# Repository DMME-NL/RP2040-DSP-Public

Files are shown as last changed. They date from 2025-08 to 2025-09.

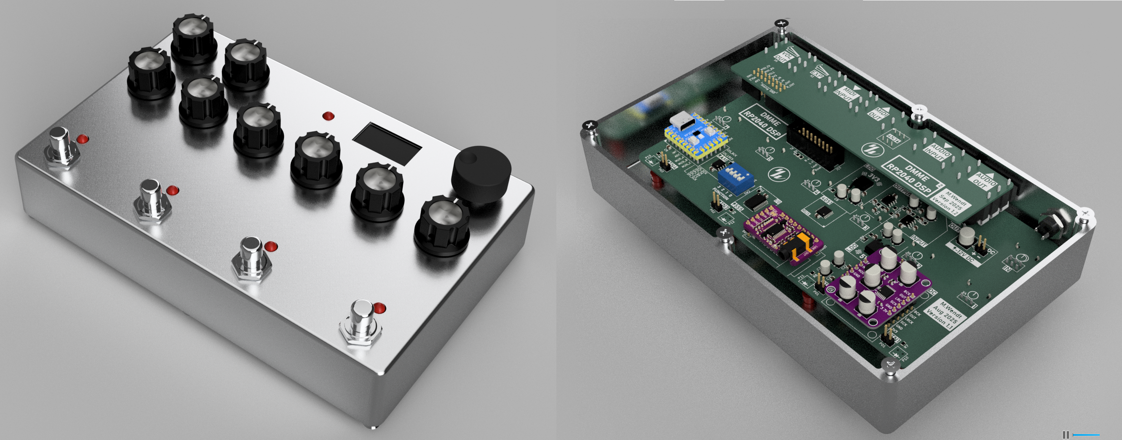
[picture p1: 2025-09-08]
Hardware/V1.2_Enclosure_Render.png

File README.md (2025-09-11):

# 🎸✨ RP2040-DSP: Multi-Effect 24-bit Audio Processor

## 🧩 Summary

RP2040-DSP is a fully modular 24-bit stereo audio effects processor built on the Raspberry Pi RP2040 microcontroller. It is designed to run real-time audio effects for guitar and other instruments, including cabinet simulation for headphone or direct recording use.

The firmware architecture is modular, supporting multiple effects that can be stacked and configured flexibly.

V1 0_Enclosure_Render

---

## 🎛️ Features & Functionality

- **24-bit stereo signal path** at 48 kHz.
- **Up to 3 simultaneous effects**, each fully configurable and ordered in series.
- Modular effect system with easy header-based integration.
- Real-time parameter control via 6 potentiometers and rotary encoder.
- OLED display for clear feedback and editing.
- Footswitch-controlled bypass and slot toggling.
- Tap-tempo support for modulation and delay-based effects.
- VU meter and signal level visualization.
- Two expression pedal inputs:
  - One dedicated to master volume.
  - One assignable to any effect parameter.

> **Note:** Total number of simultaneous effects is limited by to CPU resources and their type.
> Some features, like MIDI and expression pedal, have not been implemented as of now.

---

## 🎚️ Available Effects

### Modulation

- **Chorus:** 1, 2, or 3 short modulated delay lines with optional stereo spread via phase offset.
- **Flanger:** Single short modulated delay with optional stereo phase offset.
- **Phaser:** Multi-stage all-pass filter network with optional stereo phase offset.
- **Tremolo:** Stereo amplitude modulation with optional stereo phase offset.

### Time-based

- **Delay:** Long stereo delay with different signal path and feedback modes, uses SPI RAM buffering. 
- **Reverb:** Hall / room type reverb based on comb and all-pass filters with modualr buffer size.

### Tone shaping

- **EQ:** Multi-band EQ similar to a guitar tone-stack. Includes range control for mid frequency.

### Dynamic

- **Compressor:** Adjustable threshold, ratio, attack, release, and makeup gain.
- **Distortion, Overdrive, Fuzz:** Various analog-inspired waveshaping algorithms with tone filtering similar to the EQ.

### Speaker & Preamp simulation

- **Cabinet Sim (Speaker Sim):** Parametric approximation of guitar cabinet. Includes multiple controls for tone shaping.
- **Preamp:** Simulates preamp coloration and dynamic shaping (Marshall, VOX, Fender).

### Work-in-Progress

- **Vibrato:** Pure pitch modulation using short-time delay interpolation.

---

## ⚡ Software Architecture and Design Choices

- **Header-based modularity:** Each effect is self-contained in its own header file (`*.h`), following a consistent structure:
  - `init_*()`
  - `load_*_parms_from_memory()`
  - `update_*_params_from_pots()`
  - `process_audio_*_sample()`
- **Pot and memory sync:** Parameters load from stored memory and dynamically update when pots change. Holding down the TAP button for 5 seconds stores all the effects and settings to flash, so they can be receovered after power-down.
- **Optimized math:** Using fixed point math and lightweight approximations, reducing CPU usage without harming audio quality.
- **Dual-core structure:**
  - **Core 0:** Dedicated to real-time audio sample processing.
  - **Core 1:** Handles UI, pot reading, OLED updates.
- **SPI RAM (APS6404L):** Used for long delay lines, minimizing local RAM usage.

> **Note:** I am an embedded electronics engineer and this is my first large software project in C.
> - *.c files frustrate me because I always forget to change them after modifying a header...
> - There will be some dependencies between variabled defined and used in different *.h header files.
> - I am using global variables in places where I might not need them / should not use them. 
> - There will be inconsistencies in coding style and methods as I have been learning a lot during the course of this project.
> - This has been some journey! I intend to clean up the code once all the features are there (I promisse...)
> - I will likely forget to clean up the code, and continue development on the newer hardware versions / platforms instead...

---

## 💻 CPU Usage (250 MHz OC, 48 kHz stereo)

| Effect | CPU Peak Usage (%) |
|---|---|
| Chorus | 21% |
| Compressor | 11% |
| Delay | 49% |
| Distortion | 19% |
| EQ | 14% |
| Flanger | 18% |
| Fuzz | 24% |
| Overdrive | 24% |
| Phaser | 30% |
| Preamp | 52% |
| Reverb | 55% |
| Speaker Sim | 25% |
| Tremolo | 5% |
| Vibrato | WIP |

> **Note:** Figures above are with common effects (overdrive, preamp, etc..) processed in mono.
> All effects can be processed as fully stereo by chaging the STEREO definition in the main.c file.
> Actual performace allows the Reveb and Delay to run simultaneously depending on the sample buffer size!
---

## 🖥️ User Interface Overview

- Parameter abbreviation display with full name and value popup on change.
- Encoder-controlled effect slot assignment and navigation.
- LED blink feedback for modulation or delays.
- Footswitch toggling per effect slot, with LED status indication.
- VU meter visualizing signal levels or compressor gain reduction in real time.
- Delay UI with time settings in [ms] or tap-tempo with selectable fractions.

---

## 🔧 Hardware Overview

> Version 1.2

This design can be ordered directly from PCBWay, including assembly of the SMD components.
See the hardware folders for a complete bill of materials (ibom.html) that also includes all the modules and THT parts. 
If you do not want to use PCBway, or refuse to give me the please of a small 10% commision via their services; the KiCAD project, gerbers, and BOM are also located in this repository.

PCBway profile: https://www.pcbway.com/project/member/?bmbno=88DFECEC-9511-40

Mainboard V1.2:  https://www.pcbway.com/project/shareproject/RP2040_Multi_effect_Pedal_Mainboard_30e99e7d.html

Mainboard V2.1:  https://www.pcbway.com/project/shareproject/RP2040_Multi_effect_Pedal_Mainboard_V2_1_08d54258.html

Daughterboard:  https://www.pcbway.com/project/shareproject/RP2040_Multi_effect_Pedal_Daughterboard_25cda6b7.html

- **ADC:** PCM1808 stereo ADC module.
- **DAC:** PCM5102 stereo DAC module.
- **Regulated power:** LM78xx linear regulators.
- **Form factor:** Designed for Hammond 1950DD enclosure.
- **Input voltage:** 9–12 V DC.
- **Expression pedals:** 2 inputs, configurable.

❗NOTE: PCM1808 inputs are not attenuated and will clip with high-output pickups. The ADC has an input RC filter on-board that can be replaced by a ~100k series resistance to provide ~2x attenuation.

> **Later versions:**  PCM3060 version are have not yet been fully tested!. The concept was proven on a different PCB design and identical schematic - without any changes to the software. Although, I did not test this PCB design specificaly, it should work perfectly fine.

---

## 📜 License

The full text of the license should be found in LICENSE.txt, included as part of this repository.

This library and all accompanying code, examples, information and documentation is Copyright (C) 2025 Milan Wendt

This program is free software: you can redistribute it and/or modify it under the terms of the GNU General Public
License, version 3 as published by the Free Software Foundation.

This program is distributed in the hope that it will be useful, but WITHOUT ANY WARRANTY; without even the implied
warranty of MERCHANTABILITY or FITNESS FOR A PARTICULAR PURPOSE. See the GNU General Public License for more details.

You should have received a copy of the GNU General Public License along with this program. If not,
see <https://www.gnu.org/licenses/>.

---

🎸 Enjoy building and tweaking your own ultimate guitar multi-effects processor with RP2040-DSP!

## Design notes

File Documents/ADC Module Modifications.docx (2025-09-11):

# PCM1808 Module

This mode can have some issues depending on the vendor.

Input Filter and Attenuation

Firstly, to make sure a high-output guitar or bass does not cause unintended clipping of the signal, it is recommended to replace the input filter on the board with a 100k resistor:

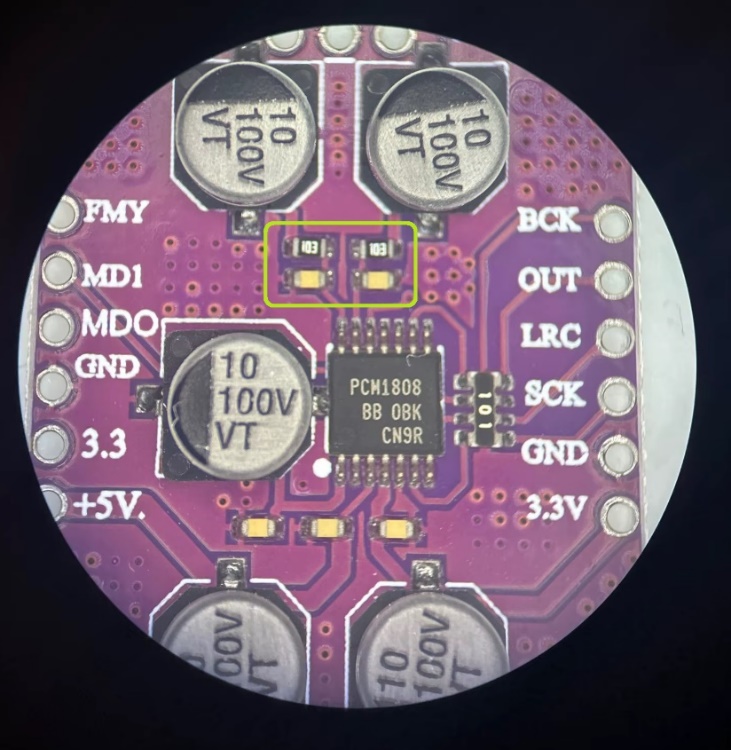
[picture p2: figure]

Simply removing the existing 0603 parts allows for soldering an 0805 resistor on the existing pads. If needed, it can placed diagonally making sure to not short the ground pad.

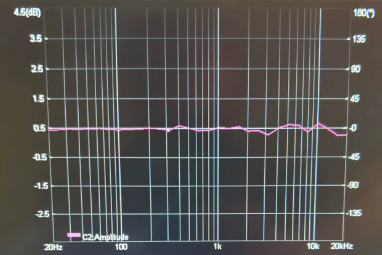
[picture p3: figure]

The modules I ordered came with wrong filter values of 10k + 10nF causing a low-pass filter of ~1.6kHz. So, replacement of these parts might be necessary depending on the vendor and manufacturer.

This bode-plot shows the frequency response if you simply short the resistor and remove the capacitor.

100k is safe, but you can play with the value to get the input level and range your application / guitar likes.

Higher values → Lower input, reduce clipping
Lower values → Higher input, improved SNR

Wrong PCB layout!

My second order arrived with a mistake in the PCB layout! (left image is the a good layout)

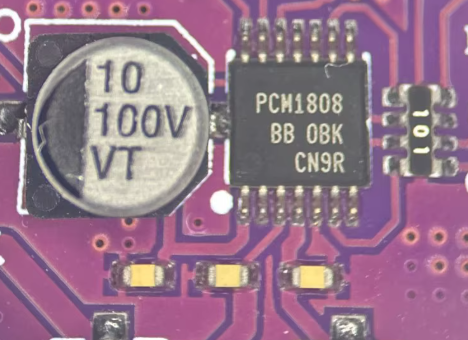
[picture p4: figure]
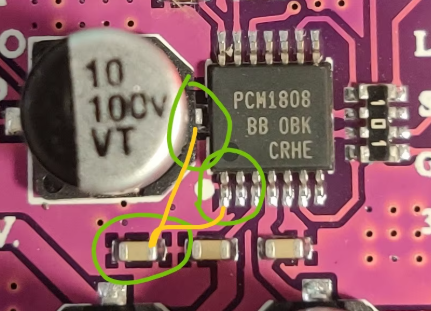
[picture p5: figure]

The right image is from another customer that tries to depict the intended traces.
This layout error cuases the bias voltage pin of the ADC to be shorted to ground!
The board will not work like this..

One way to salvage it is to cut the traces / ground plane arount the pin and solder a THT 10uF capacitor to GND. Make sure to also add a ceramic 100nF cap (just to follow the datasheet recommended values).

Optionally, the pin can be lifted instead.
Capacitor rating of > 15V should be more than enough.

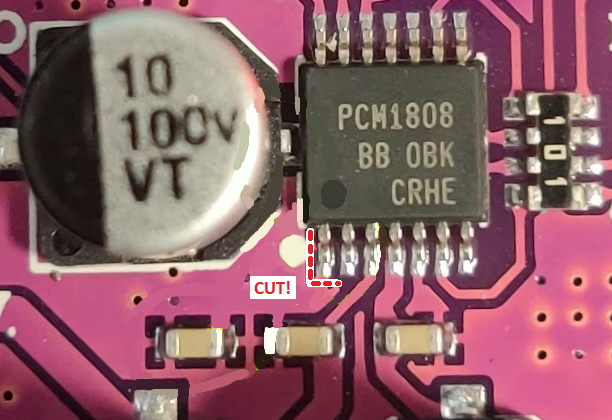
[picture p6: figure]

Just make sure to disconnect it from ground and add the two capacitors!

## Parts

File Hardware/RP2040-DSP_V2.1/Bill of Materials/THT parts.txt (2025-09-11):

RP2040 Zero:
https://nl.aliexpress.com/item/1005006865919374.html

128x64_OLED:
https://nl.aliexpress.com/item/1005006262908701.html

4N36_DIP-6_W7.62mm:
https://nl.aliexpress.com/item/1005007501324743.html

Potentiometer_Alpha_RD902F-40-00D:
https://nl.aliexpress.com/item/1005008575940833.html

Potentiometer_Alpha_RD901F-40-00D:
https://nl.aliexpress.com/item/1005005661105692.html

RotaryEncoder_Alps_EC11:
https://nl.aliexpress.com/item/4000669429876.html

Jack 6.35mm Horizontal NYS215:
https://nl.aliexpress.com/item/32963629992.html

IDC-Header_2x08_P2.54mm_Vertical	
https://nl.aliexpress.com/item/1005005963522730.html

SW_DIP_SPSTx04:
https://nl.aliexpress.com/item/10000004737395.html

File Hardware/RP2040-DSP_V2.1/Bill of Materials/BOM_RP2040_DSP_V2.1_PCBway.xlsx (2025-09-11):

 |  |  | RP2040 DSP V1.2 PCS BOM (Sample Bill of Materials)
Item # | *Designator | *Qty | Manufacturer | *Mfg Part # | Description / Value | *Package/Footprint | Type | Your Instructions / Notes
24 | C1 | 1 | Würth Elektronik | 865080343009 | CAP ALUM 100UF 20% 16V SMD | C_Elec 6.3mm | SMD | Replace with different part with same specs is accepted
16 | C17,C16 | 2 | Murata Electronics | GRM2165C1H101JA01J | CAP CER 100PF 50V C0G/NP0 0805 | 0805 | SMD | Replace with different part with same specs is accepted
8 | C21,C25,C3,C18,C12,C2,C5,C11,C23,C24,C13,C20,C10,C19,C6,C4,C29,C31 | 18 | Murata Electronics | GCM21BR71H104KA37K | CAP CER 0.1UF 50V X7R 0805 | 0805 | SMD | Replace with different part with same specs is accepted
4 | C28,C15,C8,C7,C26,C27,C22,C34,C14,C32,C33 | 11 | Würth Elektronik | 865080440002 | CAP ALUM 10UF 20% 25V SMD | C_Elec 4.3mm | SMD | Replace with different part with same specs is accepted
10 | C9,C30 | 2 | Murata Electronics | GRM216R61E105KA12D | CAP CER 1UF 25V X5R 0805 | 0805 | SMD | Replace with different part with same specs is accepted
20 | D1 | 1 | KYOCERA AVX | SD0805S040S0R5 | DIODE SCHOTTKY 40V 500MA 0805 | 0805 | SMD | Replace with different part with same specs is accepted
9 | D2,D3 | 2 | Kingbright | APT2012SRCPRV | LED RED CLEAR CHIP SMD | 0805 | SMD | Replace with different part with same specs is accepted
25 | R14 | 1 | YAGEO | RC0805FR-07220KL | RES 220K OHM 1% 1/8W 0805 | 0805 | SMD | Replace with different part with same specs is accepted
45 | R15 | 1 | YAEGO | RC0805FR-07680RL | RES 680 OHM 1% 1/8W 0805 | 0805 | SMD | Replace with different part with same specs is accepted
44 | R16 | 1 | YAEGO | RC0805FR-0710RL | RES 10 OHM 1% 1/8W 0805 | 0805 | SMD | Replace with different part with same specs is accepted
37 | R17 | 1 | YAEGO | RC0805FR-0733RL | RES 33 OHM 1% 1/8W 0805 | 0805 | SMD | Replace with different part with same specs is accepted
41 | R18 | 1 | YAEGO | RC0805FR-07220RL | RES 220 OHM 1% 1/8W 0805 | 0805 | SMD | Replace with different part with same specs is accepted
5 | R5,R22,Rp1,R6,R21,R20,R19 | 7 | YAEGO | RC0805FR-0710KL | RES 10K OHM 1% 1/8W 0805 | 0805 | SMD | Replace with different part with same specs is accepted
1 | R7,R1,R2,R9,R13,R10,R4,R3,R8 | 9 | YAEGO | RC0805FR-071KL | RES 1K OHM 1% 1/8W 0805 | 0805 | SMD | Replace with different part with same specs is accepted
2 | Rb1,Rb4,Rb3,Rb2 | 4 | YAEGO | RC0805FR-071ML | RES 1M OHM 1% 1/8W 0805 | 0805 | SMD | Replace with different part with same specs is accepted
3 | Rg1,Rg2,R11,R12 | 4 | YAEGO | RC0805FR-074K7L | RES 4.7K OHM 1% 1/8W 0805 | 0805 | SMD | Replace with different part with same specs is accepted
13 | U1 | 1 | Texas Instruments | LM78M05CDT/NOPB | IC REG LINEAR 5V 500MA TO252-3 | TO-252-3 | SMD | Replace with different part with same specs is accepted
17 | U10,U9 | 2 | Texas Instruments | NE5532DR | IC OPAMP GP 2 CIRCUIT 8SOIC | SOIC-8 | SMD | Replace with different part with same specs is accepted
12 | U13 | 1 | Advanced Monolithic Systems | AMS1117CD-3.3 | IC REG LINEAR 3.3V 1A TO252 | TO-252-3 | SMD | Replace with different part with same specs is accepted
7 | U2 | 1 | Texas Instruments | PCM3060PWR | IC AUDIO CODEC 24BIT SER 28TSSOP | TSSOP-28 | SMD
22 | U3 | 1 | Texas Instruments | CD4051BPWR | IC MUX 8:1 240OHM 16TSSOP | TSSOP-16 | SMD
14 | U5 | 1 | AP Memory | APS6404L-3SQR-SN | DRAM 64Mb QSPI PSRAM Sync Serial x1/x4 SDR | SOP-8 | SMD
21 | U6 | 1 | Texas Instruments | PCA9555DB | IC XPNDR 400KHZ I2C SMBUS 24SSOP | SSOP-24 | SMD
Need a quick and accurante quote? Need an efficient production? Please read SMT Ordering Necessary Files & Info in 1 minute. Thank you very much! (https://www.pcbway.com/smt_ordering_guide.html)
Click for Instructions on How to Create a BOM (https://www.pcbway.com/blog/PCB_Assembly/How_to_Build_a_BOM__Bill_Of_Materials_.html)

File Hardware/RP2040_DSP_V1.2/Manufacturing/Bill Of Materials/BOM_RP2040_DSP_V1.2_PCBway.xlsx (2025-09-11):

 |  |  | RP2040 DSP V1.2 PCS BOM (Sample Bill of Materials)
Item # | *Designator | *Qty | Manufacturer | *Mfg Part # | Description / Value | *Package/Footprint | Type | Your Instructions / Notes
1 | C1 | 1 | Würth Elektronik | 865080343009 | CAP ALUM 100UF 20% 16V SMD | C_Elec 6.3mm | SMD | Replace with different part with same specs is accepted
2 | C15,C8,C7,C26,C27,C23,C22,C14,C32,C33 | 10 | Würth Elektronik | 865080440002 | CAP ALUM 10UF 20% 25V SMD | C_Elec 4.3mm | SMD | Replace with different part with same specs is accepted
3 | C17,C16 | 2 | Murata Electronics | GRM2165C1H101JA01J | CAP CER 100PF 50V C0G/NP0 0805 | 0805 | SMD | Replace with different part with same specs is accepted
4 | C28,C21,C25,C3,C18,C12,C2,C5,C11,C24,C13,C20,C10,C19,C6,C4,C29,C31 | 18 | Murata Electronics | GCM21BR71H104KA37K | CAP CER 0.1UF 50V X7R 0805 | 0805 | SMD | Replace with different part with same specs is accepted
5 | C9,C30 | 2 | Murata Electronics | GRM216R61E105KA12D | CAP CER 1UF 25V X5R 0805 | 0805 | SMD | Replace with different part with same specs is accepted
6 | D1 | 1 | KYOCERA AVX | SD0805S040S0R5 | DIODE SCHOTTKY 40V 500MA 0805 | 0805 | SMD | Replace with different part with same specs is accepted
7 | D2,D3 | 2 | Kingbright | APT2012SRCPRV | LED RED CLEAR CHIP SMD | 0805 | SMD | Replace with different part with same specs is accepted
8 | R15 | 1 | YAEGO | RC0805FR-07680RL | RES 680 OHM 1% 1/8W 0805 | 0805 | SMD | Replace with different part with same specs is accepted
9 | R16 | 1 | YAEGO | RC0805FR-0710RL | RES 10 OHM 1% 1/8W 0805 | 0805 | SMD | Replace with different part with same specs is accepted
10 | R17 | 1 | YAEGO | RC0805FR-0733RL | RES 33 OHM 1% 1/8W 0805 | 0805 | SMD | Replace with different part with same specs is accepted
11 | R18 | 1 | YAEGO | RC0805FR-07220RL | RES 220 OHM 1% 1/8W 0805 | 0805 | SMD | Replace with different part with same specs is accepted
12 | R5,Rp1,R6 | 3 | YAEGO | RC0805FR-0710KL | RES 10K OHM 1% 1/8W 0805 | 0805 | SMD | Replace with different part with same specs is accepted
13 | R7,R1,R2,R9,R13,R10,R4,R3,R8 | 9 | YAEGO | RC0805FR-071KL | RES 1K OHM 1% 1/8W 0805 | 0805 | SMD | Replace with different part with same specs is accepted
14 | Rb1,Rb4,Rb3,Rb2 | 4 | YAEGO | RC0805FR-071ML | RES 1M OHM 1% 1/8W 0805 | 0805 | SMD | Replace with different part with same specs is accepted
15 | Rg1,Rg2,R11,R12 | 4 | YAEGO | RC0805FR-074K7L | RES 4.7K OHM 1% 1/8W 0805 | 0805 | SMD | Replace with different part with same specs is accepted
16 | U1 | 1 | Texas Instruments | LM78M05CDT/NOPB | IC REG LINEAR 5V 500MA TO252-3 | TO-252-3 | SMD | Replace with different part with same specs is accepted
17 | U10,U9 | 2 | Texas Instruments | NE5532DR | IC OPAMP GP 2 CIRCUIT 8SOIC | SOIC-8 | SMD | Replace with different part with same specs is accepted
18 | U13 | 1 | Advanced Monolithic Systems | AMS1117CD-3.3 | IC REG LINEAR 3.3V 1A TO252 | TO-252-3 | SMD | Replace with different part with same specs is accepted
19 | U3 | 1 | Texas Instruments | CD4051BPWR | IC MUX 8:1 240OHM 16TSSOP | TSSOP-16 | SMD
20 | U5 | 1 | AP Memory | APS6404L-3SQR-SN | DRAM 64Mb QSPI PSRAM Sync Serial x1/x4 SDR | SOP-8 | SMD
21 | U6 | 1 | Texas Instruments | PCA9555DB | IC XPNDR 400KHZ I2C SMBUS 24SSOP | SSOP-24 | SMD
Need a quick and accurante quote? Need an efficient production? Please read SMT Ordering Necessary Files & Info in 1 minute. Thank you very much! (https://www.pcbway.com/smt_ordering_guide.html)
Click for Instructions on How to Create a BOM (https://www.pcbway.com/blog/PCB_Assembly/How_to_Build_a_BOM__Bill_Of_Materials_.html)

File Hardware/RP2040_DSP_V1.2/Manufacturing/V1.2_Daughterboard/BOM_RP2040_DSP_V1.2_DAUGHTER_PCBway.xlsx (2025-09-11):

 |  |  | RP2040 DSP V1.2 PCS BOM (Sample Bill of Materials)
Item # | *Designator | *Qty | Manufacturer | *Mfg Part # | Description / Value | *Package/Footprint | Type | Your Instructions / Notes
1 | C32,C33 | 10 | Würth Elektronik | 865080440002 | CAP ALUM 10UF 20% 25V SMD | C_Elec 4.3mm | SMD | Replace with generic part with same specs is accepted
2 | C31 | 18 | Murata Electronics | GCM21BR71H104KA37K | CAP CER 0.1UF 50V X7R 0805 | 0805 | SMD | Replace with generic part with same specs is accepted
3 | R15 | 1 | YAEGO | RC0805FR-07680RL | RES 680 OHM 1% 1/8W 0805 | 0805 | SMD | Replace with generic part with same specs is accepted
4 | R16 | 1 | YAEGO | RC0805FR-0710RL | RES 10 OHM 1% 1/8W 0805 | 0805 | SMD | Replace with generic part with same specs is accepted
5 | R17 | 1 | YAEGO | RC0805FR-0733RL | RES 33 OHM 1% 1/8W 0805 | 0805 | SMD | Replace with generic part with same specs is accepted
6 | R18 | 1 | YAEGO | RC0805FR-07220RL | RES 220 OHM 1% 1/8W 0805 | 0805 | SMD | Replace with generic part with same specs is accepted
Need a quick and accurante quote? Need an efficient production? Please read SMT Ordering Necessary Files & Info in 1 minute. Thank you very much! (https://www.pcbway.com/smt_ordering_guide.html)
Click for Instructions on How to Create a BOM (https://www.pcbway.com/blog/PCB_Assembly/How_to_Build_a_BOM__Bill_Of_Materials_.html)

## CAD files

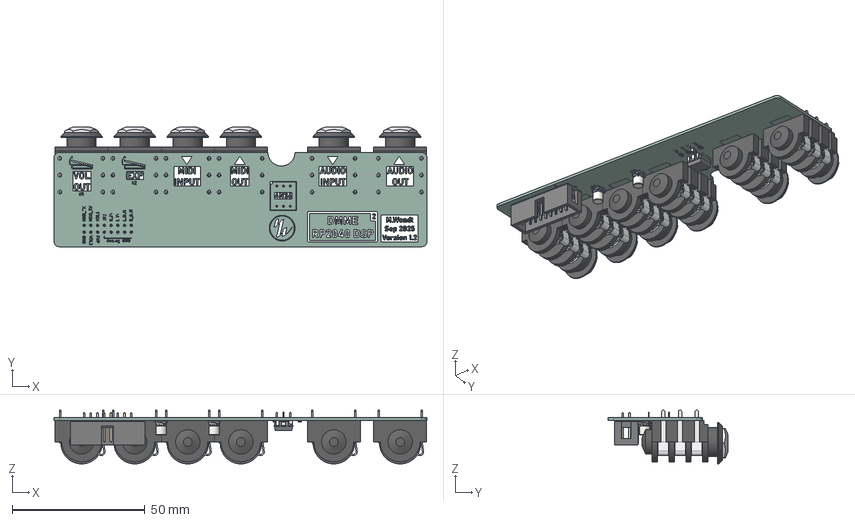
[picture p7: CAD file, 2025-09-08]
Hardware/Enclosure/RP2040_DSP_V1.2_Daughter.step
140.5 x 45.0 x 20.3 mm
Jack Socket x 6
Jack Nut x 6
Jack Nut Washer x 6
C_Elec_4x5.4 x 2
R_0805_2012Metric x 4
C_0805_2012Metric
IDC-Header_2x08_P2.54mm_Vertical
DIP-6_W7.62mm
RP2040_DSP_V1.2_silkscreen
RP2040_DSP_V1.2_PCB

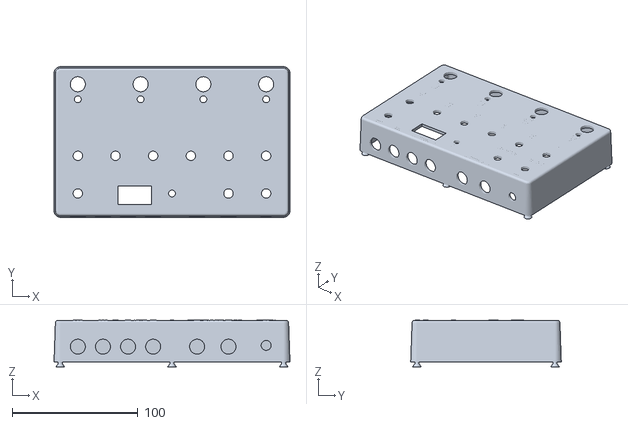
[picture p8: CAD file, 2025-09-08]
Hardware/Enclosure/RP2040 - MultEffect V1.2 Case.stl
188.0 x 120.0 x 37.1

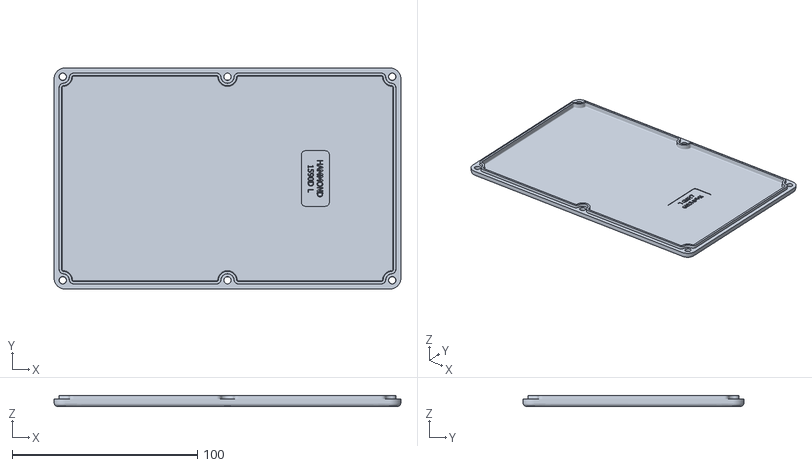
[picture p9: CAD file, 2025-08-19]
Hardware/Enclosure/RP2040 - MultEffect V1.2 Lid.stl
187.5 x 119.5 x 5.90

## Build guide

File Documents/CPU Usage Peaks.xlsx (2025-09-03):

Author: | Milan Wendt |  | Fs: | 48000 | Hz
Date: | 2025-09-02 |  | Limit | 10 | ms
 |  |  | Clock: | 250 | MHz
 |  | 128 | samples | 64 | samples | 32 | samples | 24 | samples | 16 | samples | 8 | samples
 | Effect | Peak | Actual | Peak | Actual | Peak | Actual | Peak | Actual | Peak | Actual | Peak | Actual | Note
 | Idle | 2% |  | 2% |  | 3% |  | 3% |  | 4% |  | 5%
 | Chorus | 16% | 14% | 16% | 14% | 20% | 18% | 24% | 21% | 26% | 24% | 21% | 19%
 | Compressor | 11% | 9% | 12% | 10% | 12% | 10% | 14% | 11% | 21% | 19% | 19% | 17%
 | Delay | 40% | 38% | 42% | 40% | 47% | 45% | 52% | 49% | 60% | 58% | 75% | 73%
 | Distortion | 20% | 18% | 20% | 18% | 21% | 19% | 22% | 19% | 23% | 21% | 24% | 22%
 | Equalizer | 15% | 13% | 15% | 13% | 15% | 13% | 17% | 14% | 17% | 15% | 19% | 17%
 | Flanger | 19% | 17% | 19% | 17% | 20% | 18% | 21% | 18% | 21% | 19% | 23% | 21%
 | Fuzz | 24% | 22% | 25% | 23% | 25% | 23% | 27% | 24% | 29% | 27% | 30% | 28%
 | Overdrive | 24% | 22% | 25% | 23% | 26% | 24% | 27% | 24% | 27% | 25% | 28% | 26%
 | Phaser | 28% | 26% | 28% | 26% | 30% | 28% | 33% | 30% | 50% | 48% | 60% | 58%
 | Pre - Fend | 52% | 50% | 53% | 51% | 55% | 53% | 54% | 51% | 57% | 55% | 56% | 54%
 | Pre - VOX | 51% | 49% | 52% | 50% | 52% | 50% | 54% | 51% | 56% | 54% | 58% | 56%
 | Pre - Marsh | 52% | 50% | 53% | 51% | 54% | 52% | 55% | 52% | 55% | 53% | 58% | 56%
 | Pre - Sol | 54% | 52% | 55% | 53% | 57% | 55% | 58% | 55% | 58% | 56% | 58% | 56%
 | Reverb | 56% | 54% | 56% | 54% | 58% | 56% | 59% | 56% | 60% | 58% | 62% | 60%
 | Cab Sim | 26% | 24% | 26% | 24% | 27% | 25% | 28% | 25% | 29% | 27% | 31% | 29%
 | Tremolo | 6% | 4% | 6% | 4% | 7% | 5% | 8% | 5% | 8% | 6% | 21% | 19%
 | Vibrato |  | -2% |  | -2% |  | -2% |  | -3% |  | -2% |  | -2% | Not implemented
 | Buffer time | 2.67 | ms | 1.33 | ms | 0.67 | ms | 0.50 | ms | 0.33 | ms | 0.17 | ms
 | Stereo | 5.33 | ms | 2.67 | ms | 1.33 | ms | 1.00 | ms | 0.67 | ms | 0.33 | ms
 | Measured | 6.1 | ms | 3.5 | ms | 2.2 | ms | 1.8 | ms | 1.5 | ms | 1.2 | ms
 | Max series | 1.64 | units | 2.86 | units | 4.55 | units | 5.56 | units | 6.67 | units | 8.33 | units
 | Round up | 2.00 | units | 3.00 | units | 5.00 | units | 6.00 | units | 7.00 | units | 9.00 | units
 | Delay | 12.2 | ms | 10.5 | ms | 11 | ms | 10.8 | ms | 10.5 | ms | 10.8 | ms
 | Effect / Samples | 128 | 64 | 32 | 24 | 16 | 8
 | Idle | 0% | 0% | -1% | -1% | -2%
 | Chorus | 0% | 0% | -4% | -8% | -10%
 | Compressor | 0% | -1% | -1% | -3% | -10%
 | Delay | 0% | -2% | -7% | -12% | -20%
 | Distortion | 0% | 0% | -1% | -2% | -3%
 | Equalizer | 0% | 0% | 0% | -2% | -2%
 | Flanger | 0% | 0% | -1% | -2% | -2%
 | Fuzz | 0% | -1% | -1% | -3% | -5%
 | Overdrive | 0% | -1% | -2% | -3% | -3%
 | Phaser | 0% | 0% | -2% | -5% | -22%
 | Preamp | 0% | -1% | -3% | -4% | -4%
 | Reverb | 0% | 0% | -2% | -3% | -4%
 | Cab Sim | 0% | 0% | -1% | -2% | -3%
 | Tremolo | 0% | 0% | -1% | -2% | -2%
 | Vibrato | 0% | 0% | 0% | 0% | 0%

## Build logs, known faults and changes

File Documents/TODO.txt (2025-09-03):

Selected for Development:
[V] Tap tempo for delay
[V] Fractions for delay
[V] Store settings
[V] Wear leveling in Flash
[ ] Vibrato

Nice to Have:
[ ] MIDI
[ ] Fix modulation artifacts
[ ] Wah-Wah

Not Required:
[ ] SPI RAM optimize
[ ] Effects optimize
[ ] Expression Pedal
[ ] Tap tempo for modulation effects

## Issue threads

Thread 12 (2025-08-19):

SPI RAM: Optimize speed

DMME-NL, 2025-08-19:
- Can we increase RAM clock?
Currently, response delay of MISO is causing setup/hold time issues when reading the data.
Perhaps, the sampling of the data line can be delayed / moved in relation to the generated clock.
Writing at higher speeds seems to be fine.

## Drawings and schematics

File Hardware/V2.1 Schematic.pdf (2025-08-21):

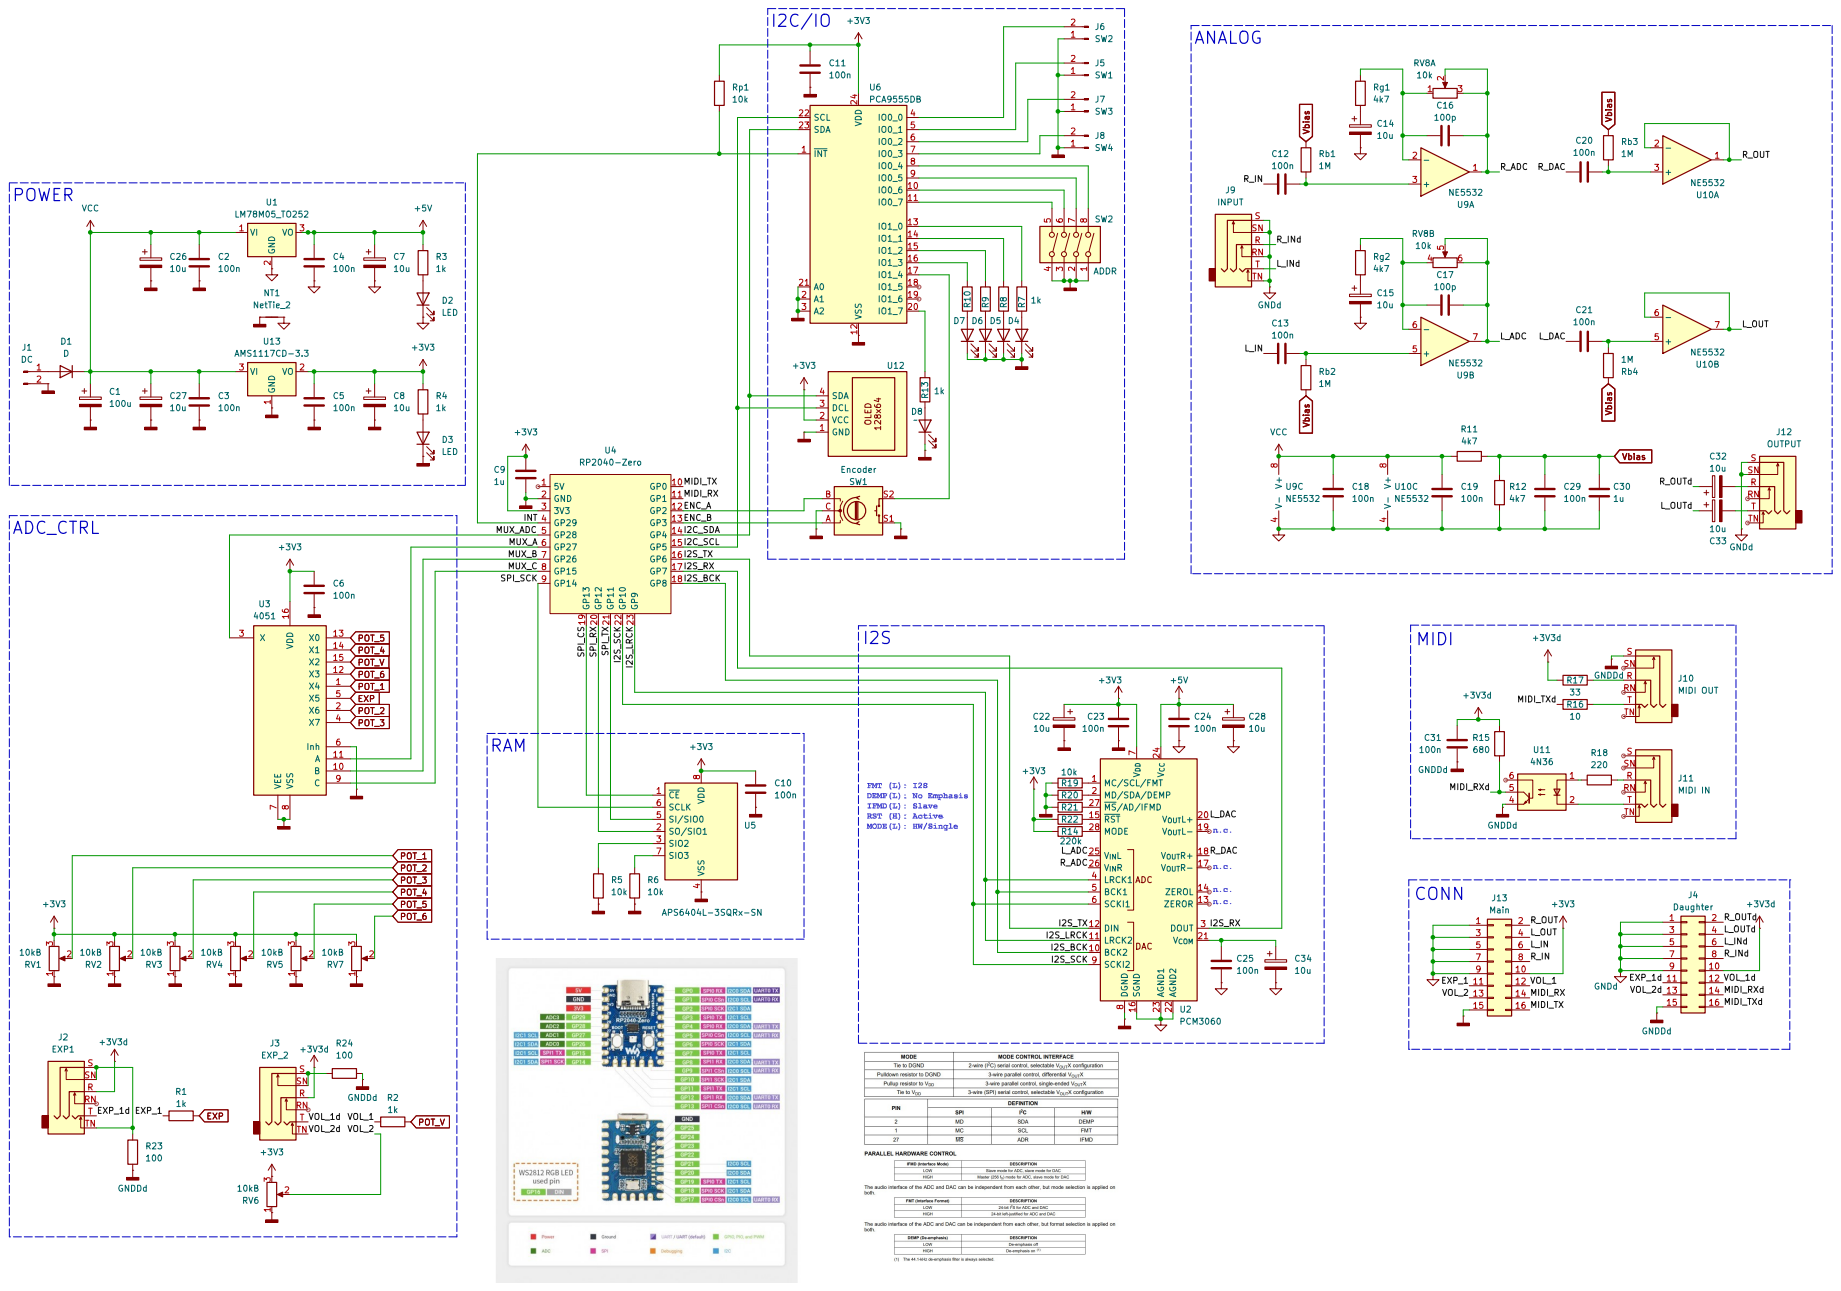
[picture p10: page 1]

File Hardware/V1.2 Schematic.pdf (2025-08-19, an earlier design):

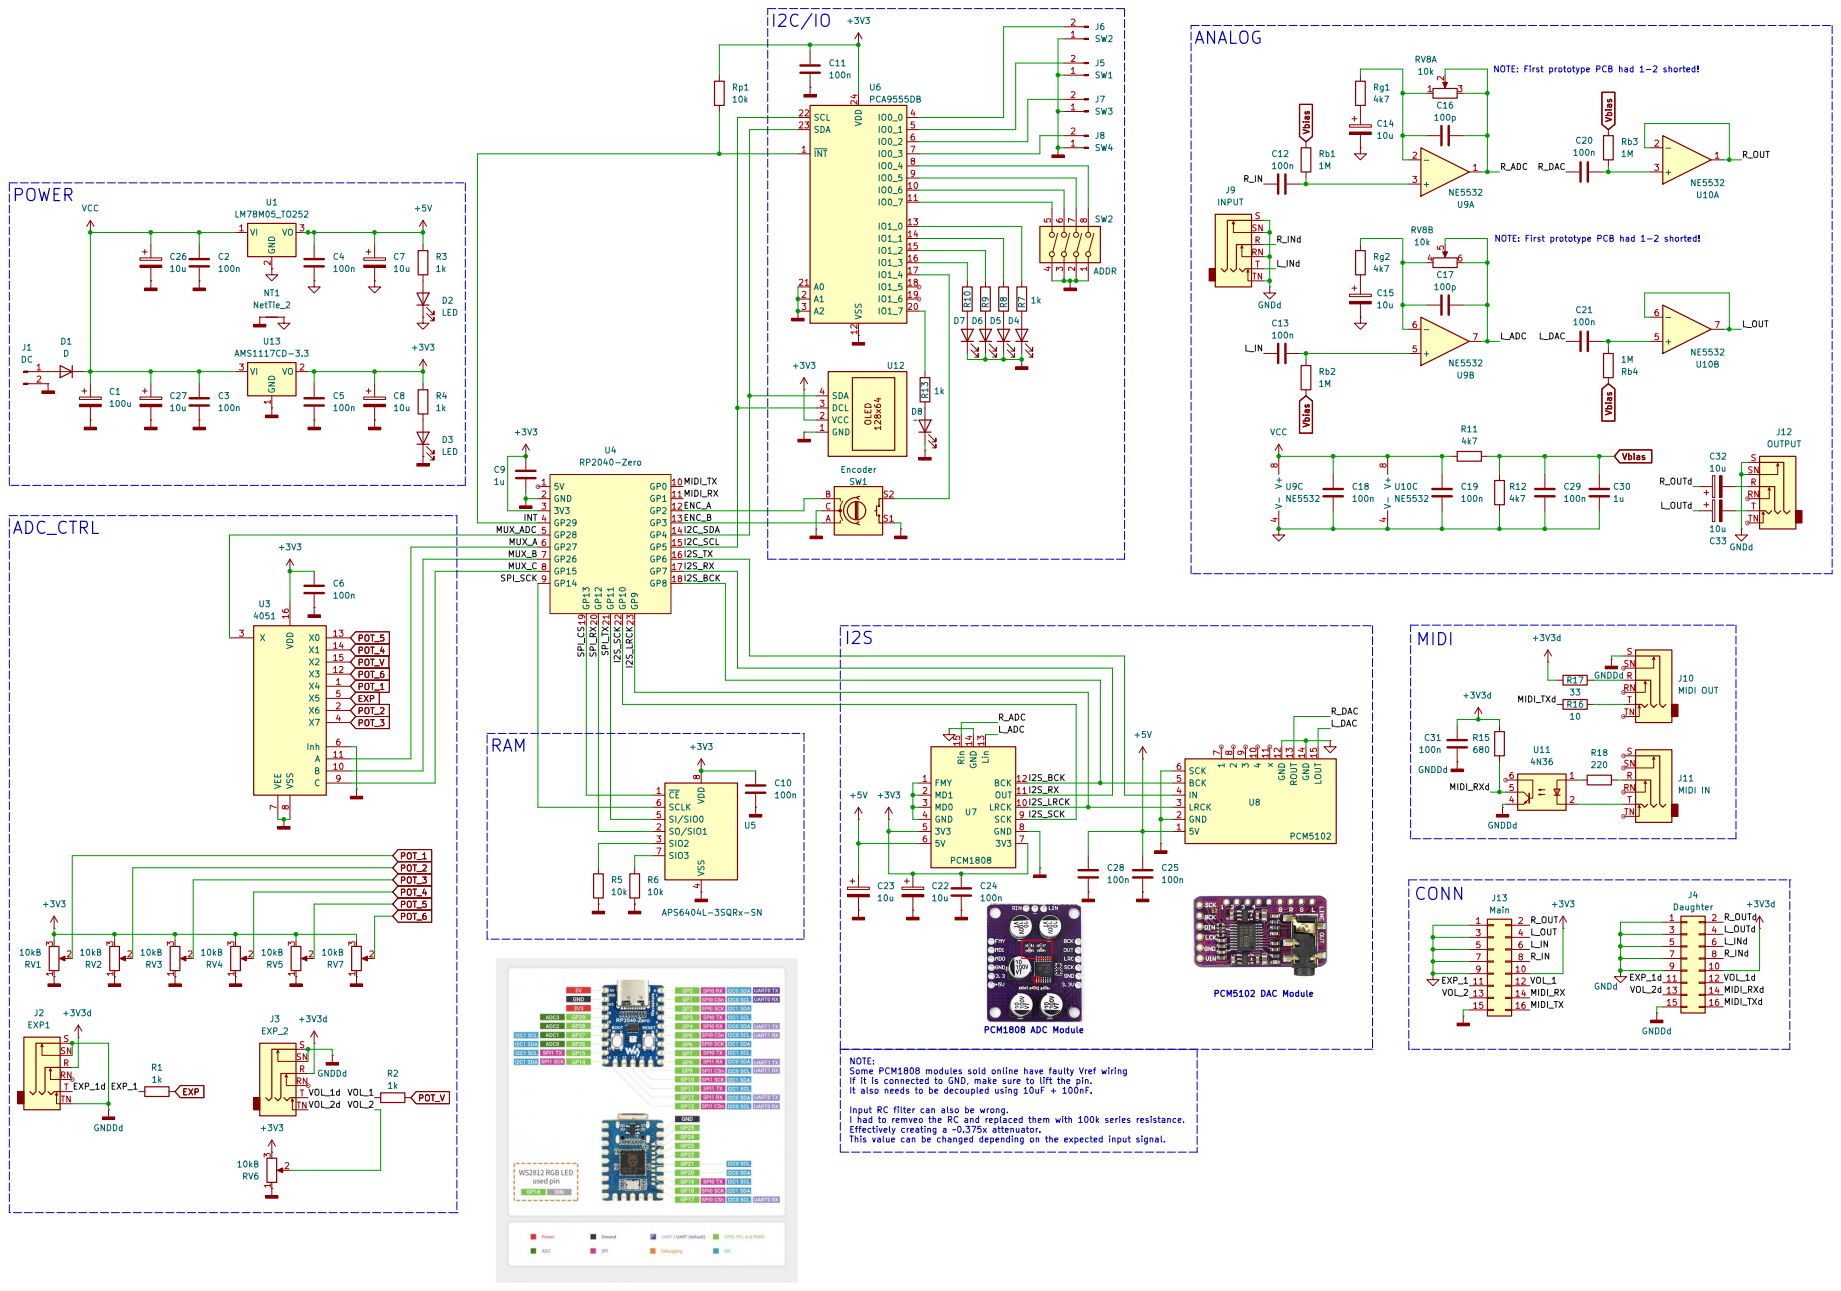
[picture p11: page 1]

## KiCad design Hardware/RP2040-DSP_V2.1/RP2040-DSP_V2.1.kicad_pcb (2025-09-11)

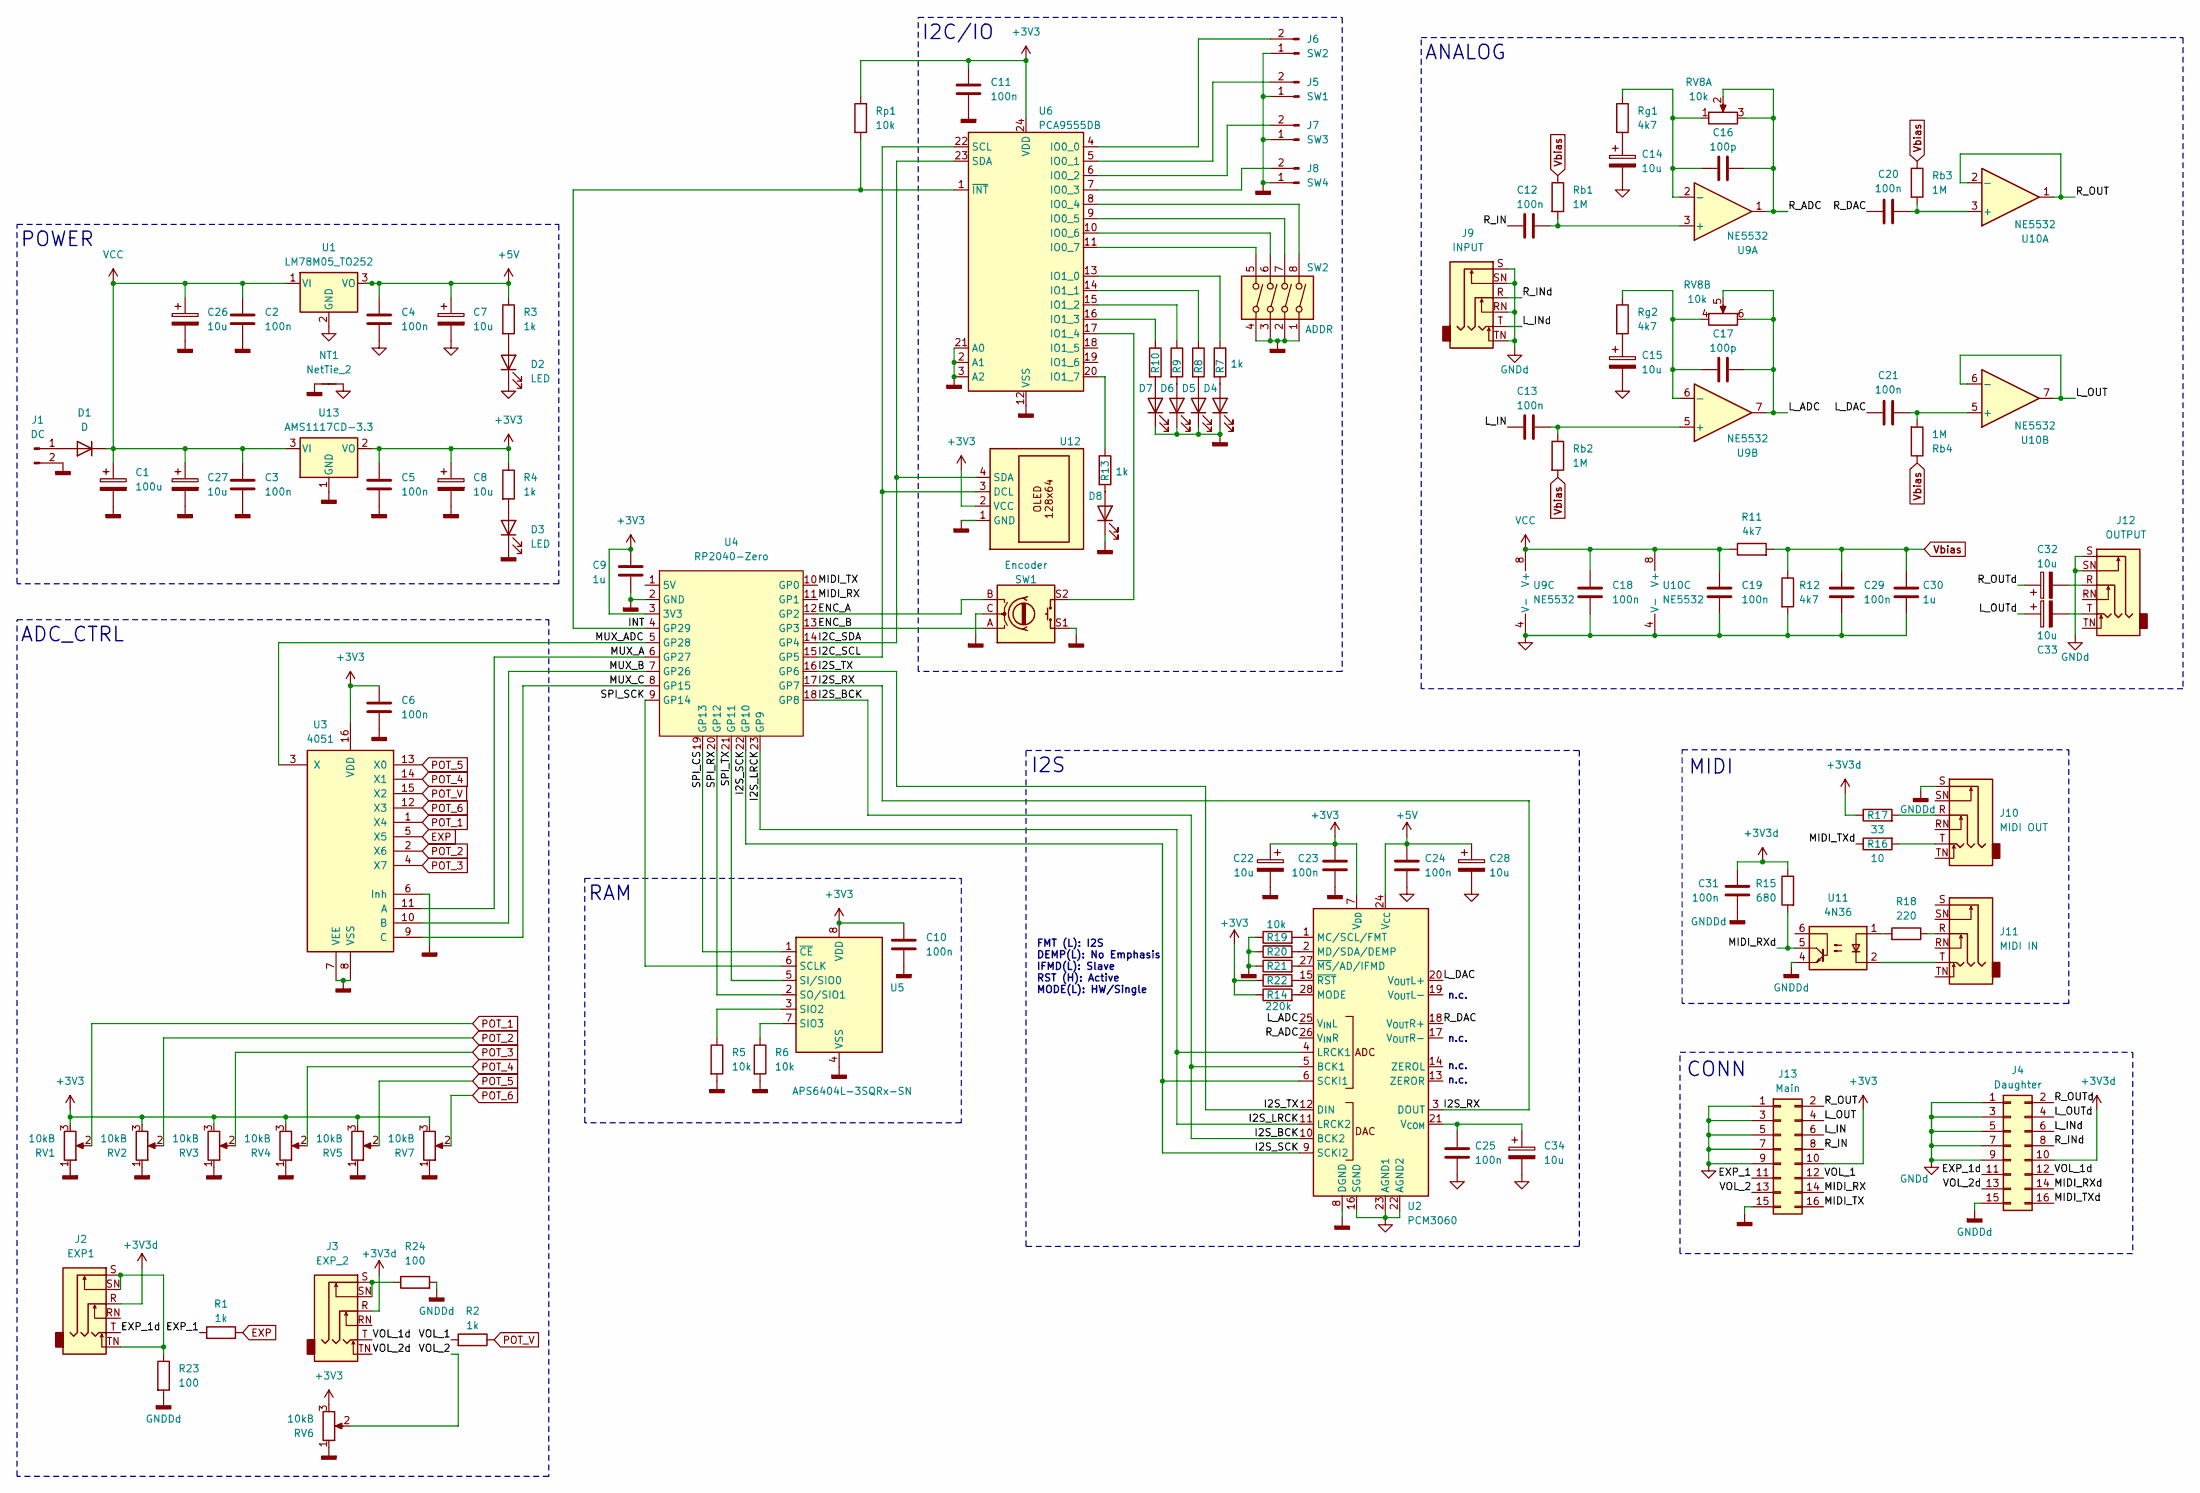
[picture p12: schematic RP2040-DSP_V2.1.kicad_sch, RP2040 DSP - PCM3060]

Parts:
C1: 100u; C_Elec_6.3x5.8
C2, C3, C4, C5, C6, C10, C11, C12, C13, C18, C19, C20, C21, C23, C24, C25, C29, C31: 100n; C_0805_2012Metric
C7, C8, C14, C15, C22, C26, C27, C28, C32, C33, C34: 10u; C_Elec_4x5.4
C9, C30: 1u; C_0805_2012Metric
C16, C17: 100p; C_0805_2012Metric
D1: D; D_0805_2012Metric
D2, D3: LED; D_0805_2012Metric
D4, D5, D6, D7, D8: LED; LED_D5.0mm
J1: DC; PinHeader_1x02_P2.54mm_Vertical
J2: EXP1; Jack 6.35mm Horizontal
J3: EXP_2; Jack 6.35mm Horizontal
J4: Daughter; IDC-Header_2x08_P2.54mm_Vertical
J5: SW1; PinHeader_1x02_P2.54mm_Vertical
J6: SW2; PinHeader_1x02_P2.54mm_Vertical
J7: SW3; PinHeader_1x02_P2.54mm_Vertical
J8: SW4; PinHeader_1x02_P2.54mm_Vertical
J9: INPUT; Jack 6.35mm Horizontal
J10: MIDI OUT; Jack 6.35mm Horizontal
J11: MIDI IN; Jack 6.35mm Horizontal
J12: OUTPUT; Jack 6.35mm Horizontal
J13: Main; IDC-Header_2x08_P2.54mm_Vertical
NT1: NetTie_2; NetTie-2_SMD_Pad2.0mm
R1, R2, R3, R4, R7, R8, R9, R10, R13: 1k; R_0805_2012Metric
R5, R6, R19, R20, R21, R22: 10k; R_0805_2012Metric
R11, R12: 4k7; R_0805_2012Metric
R14: 220k; R_0805_2012Metric
R15: 680; R_0805_2012Metric
R16: 10; R_0805_2012Metric
R17: 33; R_0805_2012Metric
R18: 220; R_0805_2012Metric
R23, R24: 100; R_0805_2012Metric
RV1, RV2, RV3, RV4, RV5, RV6, RV7: 10kB; Potentiometer_Alpha_RD901F-40-00D
RV8: 10k; Potentiometer_Alpha_RD902F-40-00D
Rb1, Rb2, Rb3, Rb4: 1M; R_0805_2012Metric
Rg1, Rg2: 4k7; R_0805_2012Metric
Rp1: 10k; R_0805_2012Metric
SW1: Encoder; RotaryEncoder_Alps_EC11
SW2: ADDR; SW_DIP_SPSTx04_Slide_9.78x12.34mm_W7.62mm_P2.54mm
U1: LM78M05_TO252; TO-252-2
U2: PCM3060; TSSOP-28_4.4x9.7mm_P0.65mm
U3: 4051; TSSOP-16_4.4x5mm_P0.65mm
U4: RP2040-Zero; RP2040 Zero Header
U5: APS6404L-3SQRx-SN; SOIC-8_3.9x4.9mm_P1.27mm
U6: PCA9555DB; SSOP-24_5.3x8.2mm_P0.65mm
U9, U10: NE5532; SOIC-8_3.9x4.9mm_P1.27mm
U11: 4N36; DIP-6_W7.62mm
U12: 128x64OLED
U13: AMS1117CD-3.3; TO-252-3_TabPin2

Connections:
+3V3: C5.1, C6.1, C8.1, C9.1, C10.1, C11.1, C22.1, C23.1, J13.10, R4.1, R14.1, R22.1, RV1.3, RV2.3, RV3.3, RV4.3, RV5.3, RV6.3, RV7.3, Rp1.1, U2.7 (V_{DD}), U3.16 (VDD), U4.3 (3V3), U5.8 (VDD), U6.24 (VDD), U12.2 (VCC), U13.2 (VO)
+3V3d: C31.1, J2.R, J3.R, J4.10, R15.1, R17.1
+5V: C4.1, C7.1, C24.1, C28.1, R3.1, U1.3 (VO), U2.24 (V_{CC})
/ENC_A: SW1.B, U4.12 (GP2)
/ENC_B: SW1.A, U4.13 (GP3)
/EXP_1: J13.11, R1.2
/EXP_1d: J2.T, J4.11
/I2C_SCL: U4.15 (GP5), U6.22 (SCL), U12.3 (DCL)
/I2C_SDA: U4.14 (GP4), U6.23 (SDA), U12.4 (SDA)
/I2S_BCK: U2.5 (BCK1), U2.10 (BCK2), U4.18 (GP8)
/I2S_LRCK: U2.4 (LRCK1), U2.11 (LRCK2), U4.23 (GP9)
/I2S_RX: U2.3 (DOUT), U4.17 (GP7)
/I2S_SCK: U2.6 (SCKI1), U2.9 (SCKI2), U4.22 (GP10)
/I2S_TX: U2.12 (DIN), U4.16 (GP6)
/INT: Rp1.2, U4.4 (GP29), U6.1 (~INT)
/L_ADC: C17.1, RV8.5, RV8.6, U2.25 (V_{IN}L), U9.7
/L_DAC: C21.1, U2.20 (V_{OUT}L+)
/L_IN: C13.1, J13.6
/L_INd: J4.6, J9.T
/L_OUT: J13.4, U10.6 (-), U10.7
/L_OUTd: C33.1, J4.4
/MIDI_RX: J13.14, U4.11 (GP1)
/MIDI_RXd: J4.14, R15.2, U11.5
/MIDI_TX: J13.16, U4.10 (GP0)
/MIDI_TXd: J4.16, R16.1
/MUX_A: U3.11 (A), U4.6 (GP27)
/MUX_ADC: U3.3 (X), U4.5 (GP28)
/MUX_B: U3.10 (B), U4.7 (GP26)
/MUX_C: U3.9 (C), U4.8 (GP15)
/R_ADC: C16.1, RV8.2, RV8.3, U2.26 (V_{IN}R), U9.1
/R_DAC: C20.1, U2.18 (V_{OUT}R+)
/R_IN: C12.1, J13.8
/R_INd: J4.8, J9.R
/R_OUT: J13.2, U10.1, U10.2 (-)
/R_OUTd: C32.1, J4.2
/SPI_CS: U4.19 (GP13), U5.1 (~CE)
/SPI_RX: U4.20 (GP12), U5.2 (SO/SIO1)
/SPI_SCK: U4.9 (GP14), U5.6 (SCLK)
/SPI_TX: U4.21 (GP11), U5.5 (SI/SIO0)
/VOL_1: J13.12, R2.2
/VOL_1d: J3.T, J4.12
/VOL_2: J13.13, RV6.2
/VOL_2d: J3.TN, J4.13
EXP: R1.1, U3.5 (X5)
GND: C4.2, C7.2, C14.2, C15.2, C18.2, C19.2, C24.2, C25.2, C28.2, C29.2, C30.2, C34.2, D2.1 (K), J13.1, J13.3, J13.5, J13.7, J13.9, NT1.2, R12.2, U1.2 (GND), U2.16 (SGND), U2.22 (AGND2), U2.23 (AGND1), U9.4 (V-), U10.4 (V-)
GNDD: C1.2, C2.2, C3.2, C5.2, C6.2, C8.2, C9.2, C10.2, C11.2, C22.2, C23.2, C26.2, C27.2, D3.1 (K), D4.1 (K), D5.1 (K), D6.1 (K), D7.1 (K), D8.1 (K), J1.2, J5.1, J6.1, J7.1, J8.1, J13.15, NT1.1, R5.2, R6.2, R19.1, R20.1, R21.1, RV1.1, RV2.1, RV3.1, RV4.1, RV5.1, RV6.1, RV7.1, SW1.C, SW1.MP, SW1.S1, SW2.1, SW2.2, SW2.3, SW2.4, U2.8 (DGND), U3.6 (Inh), U3.7 (VEE), U3.8 (VSS), U4.2 (GND), U5.4 (VSS), U6.2 (A1), U6.3 (A2), U6.12 (VSS), U6.21 (A0), U12.1 (GND), U13.1 (GND)
GNDd: J4.1, J4.3, J4.5, J4.7, J4.9, J9.RN, J9.S, J9.SN, J9.TN, J12.S, J12.SN
unnamed: C14.1, Rg1.2
unnamed: C15.1, Rg2.2
unnamed: C32.2, J12.R
unnamed: C33.2, J12.T
unnamed: D1.2 (A), J1.1
unnamed: D2.2 (A), R3.2
unnamed: D3.2 (A), R4.2
unnamed: D4.2 (A), R7.2
unnamed: D5.2 (A), R8.2
unnamed: D6.2 (A), R9.2
unnamed: D7.2 (A), R10.2
unnamed: D8.2 (A), R13.2
unnamed: J5.2, U6.5 (IO0_1)
unnamed: J6.2, U6.4 (IO0_0)
unnamed: J7.2, U6.6 (IO0_2)
unnamed: J8.2, U6.7 (IO0_3)
unnamed: J10.R, R17.2
unnamed: J10.T, R16.2
unnamed: J11.R, R18.1
unnamed: J11.T, U11.2
unnamed: R18.2, U11.1
unnamed: R19.2, U2.1 (MC/SCL/FMT)
unnamed: R20.2, U2.2 (MD/SDA/DEMP)
unnamed: R14.2, U2.28 (MODE)
unnamed: C25.1, C34.1, U2.21 (V_{COM})
unnamed: R21.2, U2.27 (~MS/AD/IFMD)
unnamed: R22.2, U2.15 (~RST)
unnamed: R5.1, U5.3 (SIO2)
unnamed: R6.1, U5.7 (SIO3)
unnamed: SW2.8, U6.8 (IO0_4)
unnamed: SW2.7, U6.9 (IO0_5)
unnamed: SW2.6, U6.10 (IO0_6)
unnamed: SW2.5, U6.11 (IO0_7)
unnamed: R7.1, U6.13 (IO1_0)
unnamed: R8.1, U6.14 (IO1_1)
unnamed: R9.1, U6.15 (IO1_2)
unnamed: R10.1, U6.16 (IO1_3)
unnamed: SW1.S2, U6.17 (IO1_4)
unnamed: R13.1, U6.20 (IO1_7)
unnamed: C12.2, Rb1.2, U9.3 (+)
unnamed: C16.2, RV8.1, Rg1.1, U9.2 (-)
unnamed: C13.2, Rb2.1, U9.5 (+)
unnamed: C17.2, RV8.4, Rg2.1, U9.6 (-)
unnamed: C20.2, Rb3.2, U10.3 (+)
unnamed: C21.2, Rb4.2, U10.5 (+)
POT_1: RV1.2, U3.1 (X4)
POT_2: RV2.2, U3.2 (X6)
POT_3: RV3.2, U3.4 (X7)
POT_4: RV4.2, U3.14 (X1)
POT_5: RV5.2, U3.13 (X0)
POT_6: RV7.2, U3.12 (X3)
POT_V: R2.1, U3.15 (X2)
VCC: C1.1, C2.1, C3.1, C18.1, C19.1, C26.1, C27.1, D1.1 (K), R11.1, U1.1 (VI), U9.8 (V+), U10.8 (V+), U13.3 (VI)
Vbias: C29.1, C30.1, R11.2, R12.1, Rb1.1, Rb2.2, Rb3.1, Rb4.1

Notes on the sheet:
ANALOG
n.c.
MIDI
ADC_CTRL
RAM
CONN
FMT (L): I2S DEMP(L): No Emphasis IFMD(L): Slave RST (H): Active MODE(L): HW/Single
POWER
I2C/IO
I2S

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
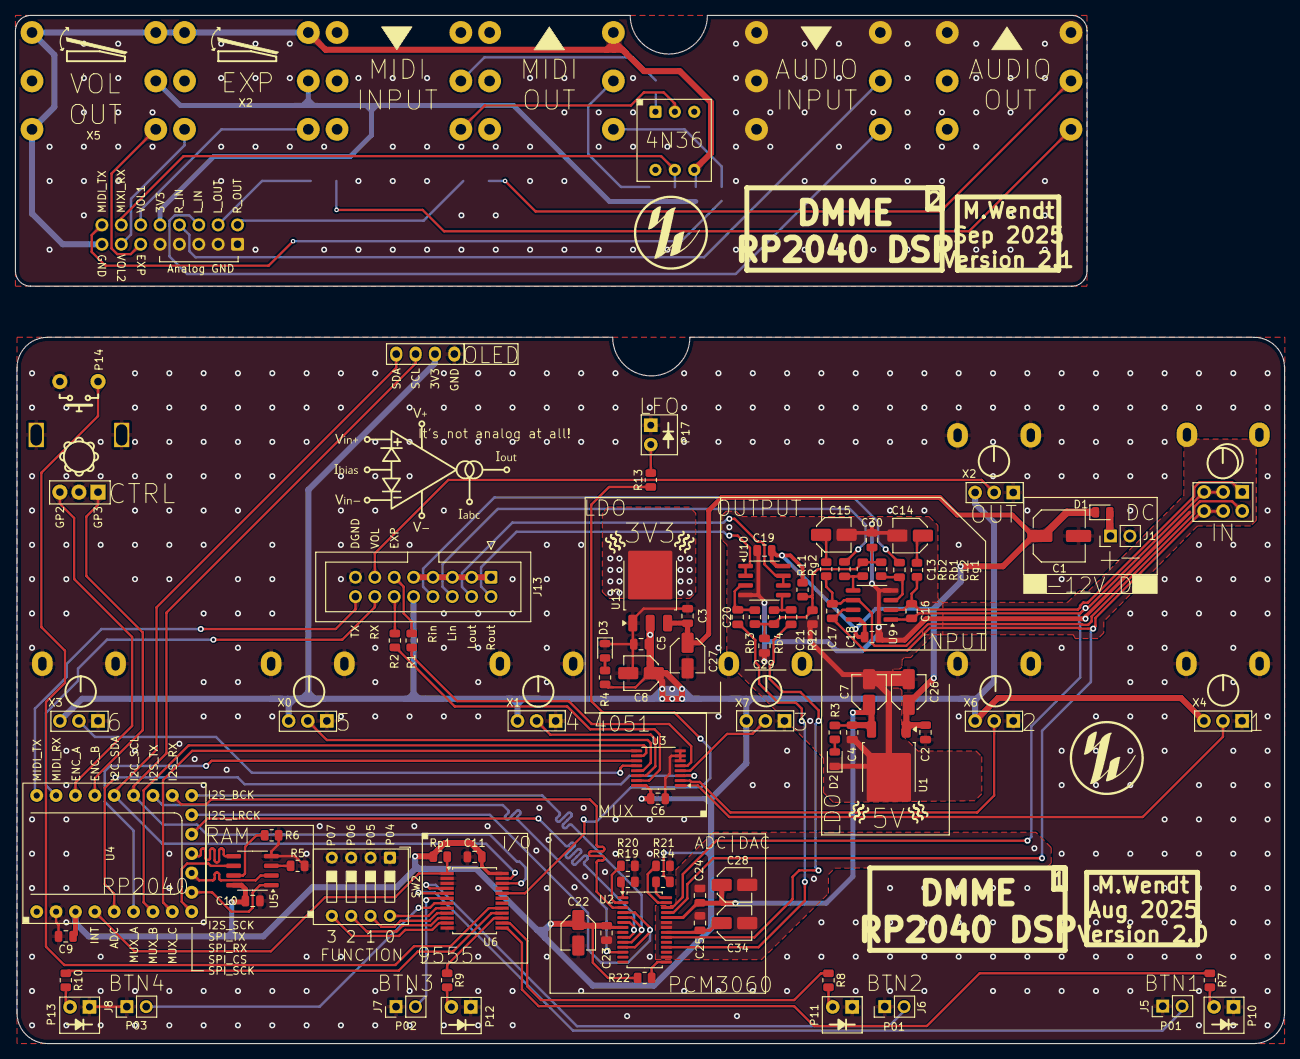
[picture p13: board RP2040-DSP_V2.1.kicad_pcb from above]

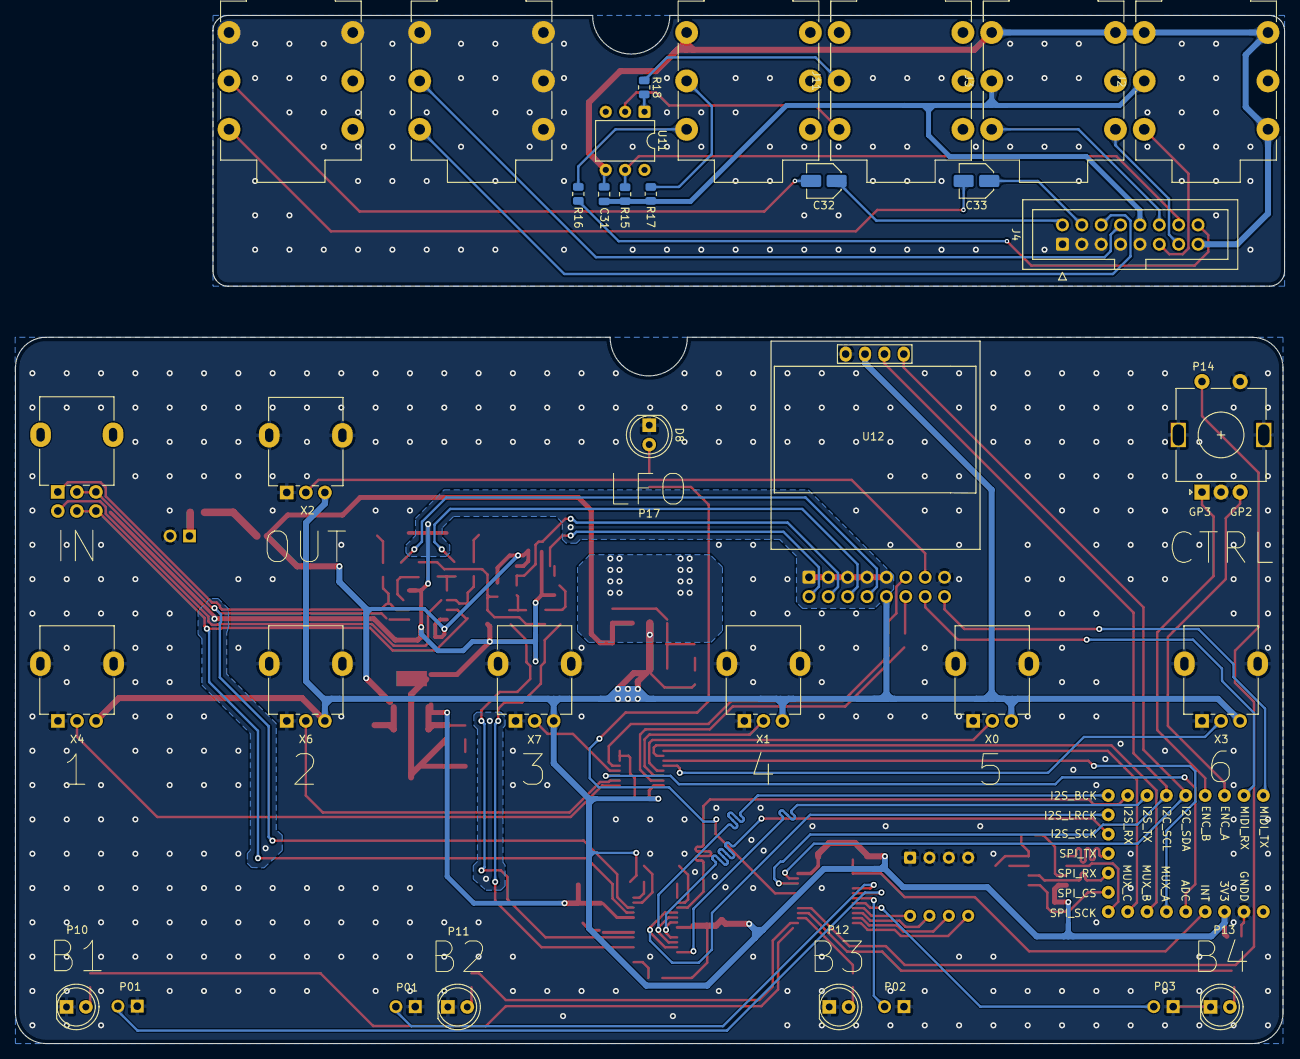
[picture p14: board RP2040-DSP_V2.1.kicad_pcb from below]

Board: 2 copper layers, 166.2 x 92.6 mm, 106 parts (30 on the bottom side), 102 nets.

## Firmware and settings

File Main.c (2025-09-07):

/* 
 * Author: Milan Wendt
 * Date:   2025-09-03
 *
 * Copyright (c) 2025 Milan Wendt
 *
 * This file is part of the RP2040-DSP project.
 *
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
 * RP2040 DSP is distributed in the hope that it will be useful, but WITHOUT ANY WARRANTY; 
 * without even the implied warranty of MERCHANTABILITY or FITNESS FOR A PARTICULAR PURPOSE.
 * See the GNU General Public License for more details.
 *
 * You should have received a copy of the GNU General Public License along with this project. 
 * If not, see <https://www.gnu.org/licenses/>.
 */

#include <stdio.h>
#include <string.h>
#include <stdlib.h>
#include <time.h>
#include <math.h>
#include <stdbool.h>

// Pico SDK headers
#include "pico/stdlib.h"
#include "pico/binary_info.h"
#include "pico/time.h"
#include "pico/multicore.h"

// Include hardware headers
#include "hardware/dma.h"
#include "hardware/clocks.h"
#include "hardware/structs/timer.h"

// SSD1306 OLED display headers
#include "font.h"
#include "ssd1306.h"

// Include I2S library for audio processing
#include "i2s.h"

// Include SPI ram
#include "spi_ram.h"

// ============================================================================
// === TIming & Debugging =====================================================
// ============================================================================

// These do not represent real frequencies
// Overclocking system clock causes strange behavior 
// === CONFIGURATION CONSTANTS ===
#define SYSTEM_CLOCK_MHZ     250   // 250 MHz system clock
#define PERIPHERAL_CLOCK_MHZ 125   // 100 MHz peripheral clock
#define SPI_TARGET_HZ         42   // 42 MHz
#define I2C_TARGET_HZ       1000   // 1000 kHz

// Enable debugging features
#define SHOW_CPU            1  // Show CPU usage in the UI
#define DEBUG               1  // Enable debug mode for additional logging
#define PRINT_POT_VALUE     0  // Print POTS values to console (on change)
#define PRINT_IO            0  // Print GPIO values to console (on change)
#define PRINT_ACTION        0  // Print actions to console

#define PRINT_CPU           0  // Print CPU usage       in DEBUG
#define PRINT_RAM           0  // Print RAM usage       in DEBUG
#define PRINT_FLASH         0  // Print FLASH usage     in DEBUG
#define PRINT_EFFECTS       0  // Print EFEFCTS status  in DEBUG
#define PRINT_CLOCK         0  // Print CLOCK INFO info in DEBUG
#define PRINT_I2S           0  // Print I2S debug info  in DEBUG

// When no hardware is connected, we can use the default LED state
uint8_t default_led_state = 0x01;

// Process gain and compression in stereo?
// This will cause the loss of stereo channels when using other effects in front!
#define STEREO  false 

// Alarm interval in microseconds
#define DEBUG_INTERVAL_US   1000000  //  1.0  second
#define CPU_INTERVAL_US      500000  //  0.5  second
#define LED_INTERVAL_US       30000  //  30Hz  ~30ms
#define DISPLAY_INTERVAL_US   40000  //  25Hz  ~40ms
#define CONTROL_INTERVAL_US   10000  //  100Hz ~10ms

// Hold tap button for this long to save settings
#define HOLD_FOR_SAVE       5000000  //  5.0 seconds

// ============================================================================
// === Global Variables & Timers ==============================================
// ============================================================================

uint8_t selected_slot    = 0;       // Index of selected parameter (0–3)
bool toggle_lfo_led_flag = false;   // Toggle LED for LFO effect
bool lfo_update_led_flag = true;    // Flag to update LFO phase
bool updateDelayFlag     = false;   // Flag to signal delay parameter update

// CPU usage variables
float cpu0_peak_usage = 0.0f;        // Peak CPU usage in percentage
float cpu1_peak_usage = 0.0f;        // Peak CPU usage in percentage
uint64_t cpu0_peak_us = 0;           // Peak CPU usage in microseconds
uint64_t cpu1_peak_us = 0;           // Peak CPU usage in microseconds

// timers for various intervals
absolute_time_t last_pot_change_time;
static uint64_t last_print_time_us = 0;

// Global tap interval in milliseconds, initially 0 (no tempo)
uint32_t tap_interval_ms = 500;
bool tap_tempo_active_l = false;
bool tap_tempo_active_r = false;
bool activate_tap_flag = false;

// Delay time global for drawing the display
uint32_t delay_samples_l = 48000;
uint32_t delay_samples_r = 48000;

// Falsh saving flags
volatile bool save_request = false;         // Core1 -> Core0 request
volatile bool saving_in_progress = false;   // Core0 -> Core1 status
volatile bool ui_park_req = false;  // Core0 asks Core1 to park
volatile bool ui_park_ack = false;  // Core1 acknowledges it's parked

// Include the files where we dumped some of the code
#include "io.h"
#include "ui_main.h"
#include "var_conversion.h"
#include "audio.h"
#include "flash.h"

// Update on single-pot change for the selected preamp
static inline void update_preamp_from_pots(int changed_pot){
    if (changed_pot < 0 || changed_pot > 5) return;
    storedPreampPotValue[selected_preamp_style][changed_pot] = pot_value[changed_pot];
    switch (selected_preamp_style) {
        case FENDER:
            load_fender_params_from_memory();   break;
        case VOX_AC:
            load_vox_params_from_memory();      break;
        case MARSHALL:
            load_marshall_params_from_memory(); break;
        case SOLDANO:
            load_slo_params_from_memory(); break;
    }
}

// ============================================================================
// === POT changes and effects ================================================
// ============================================================================

typedef void (*EffectUpdateFn)(int changed_pot);

static EffectUpdateFn effect_param_updaters[NUM_EFFECTS] = {
    [CHRS_EFFECT_INDEX]     = update_chorus_params_from_pots,
    [COMP_EFFECT_INDEX]     = update_compressor_params_from_pots,
    [DELAY_EFFECT_INDEX]    = update_delay_params_from_pots,
    [DS_EFFECT_INDEX]       = update_distortion_params_from_pots,
    [EQ_EFFECT_INDEX]       = update_eq_params_from_pots,
    [FLNG_EFFECT_INDEX]     = update_flanger_params_from_pots,
    [FZ_EFFECT_INDEX]       = update_fuzz_params_from_pots,
    [OD_EFFECT_INDEX]       = update_overdrive_params_from_pots,
    [PHSR_EFFECT_INDEX]     = update_phaser_params_from_pots,
    [PREAMP_EFFECT_INDEX]   = update_preamp_from_pots,
    [REVB_EFFECT_INDEX]     = update_reverb_params_from_pots,
    [CAB_SIM_EFFECT_INDEX]  = update_speaker_sim_params_from_pots,
    [TREM_EFFECT_INDEX]     = update_tremolo_params_from_pots,
    [VIBR_EFFECT_INDEX]     = update_vibrato_params_from_pots
};

// ============================================================================
// === CPU RESOURCES ==========================================================
// ============================================================================

// === CPU0 usage ===
static volatile uint32_t interrupt_count = 0;
static volatile uint64_t total_duration_us = 0;
static uint64_t cpu0_loop_start_time_us = 0;

static inline void cpu0_task_start(void) {
    cpu0_loop_start_time_us = time_us_64();
}

static inline void cpu0_task_end(void) {
    uint64_t duration = time_us_64() - cpu0_loop_start_time_us;

    if (duration > cpu0_peak_us) {
        cpu0_peak_us = duration;
        cpu0_peak_usage = ((float)duration / sample_period_us) * 100.0f;
    }
}

void CPU_usage_counter() {
    static uint64_t last_reset_time = 0;
    uint64_t now = time_us_64();
    // Reset peak every 0.5 seconds (or any interval you want)
    if (now - last_reset_time >= CPU_INTERVAL_US) {
        last_reset_time = now;
        cpu0_peak_us = 0;
        cpu0_peak_usage = 0.0f;
    }
}

//=== CPU1 respource counter ===
uint64_t cpu1_loop_start_time_us = 0;
// CPU1 average tracking
static uint64_t cpu1_total_us = 0;
static uint32_t cpu1_sample_count = 0;
float cpu1_avg_usage = 0.0f;

static inline void cpu1_task_start(void) {
    cpu1_loop_start_time_us = time_us_64();
}

static inline void cpu1_task_end(void) {
    uint64_t duration = time_us_64() - cpu1_loop_start_time_us;

    // Peak tracking
    if (duration > cpu1_peak_us) {
        cpu1_peak_us = duration;
    }

    // Average tracking
    cpu1_total_us += duration;
    cpu1_sample_count++;
}


void update_cpu1_usage(float sample_period_us) {
    // Peak usage
    cpu1_peak_usage = ((float)cpu1_peak_us / sample_period_us) * 100.0f;

    // Average usage
    if (cpu1_sample_count > 0) {
        float avg_duration = (float)cpu1_total_us / cpu1_sample_count;
        cpu1_avg_usage = (avg_duration / sample_period_us) * 100.0f;
    } else {
        cpu1_avg_usage = 0.0f;
    }
}

void reset_cpu1_time(void){
    cpu1_peak_us = 0;
    cpu1_total_us = 0;
    cpu1_sample_count = 0;
}

// ============================================================================
// === AUDIO Processing =======================================================
// ============================================================================

// I2S configuration
static __attribute__((aligned(8))) pio_i2s i2s;

// Selected effects processing per sample
static inline __attribute__((always_inline))
void process_selected_effect_block(int slot, int32_t* in_l, int32_t* in_r, size_t frames) {
    switch (selectedEffects[slot]) {
        case CHRS_EFFECT_INDEX:
            chorus_process_block(in_l, in_r, frames, selected_chorus_mode); break;

        case COMP_EFFECT_INDEX:
            compressor_process_block(in_l, in_r, frames, STEREO); break;

        case DELAY_EFFECT_INDEX:
            delay_process_block(in_l, in_r, frames, selected_delay_mode, true); break;

        case DS_EFFECT_INDEX:
            distortion_process_block(in_l, in_r, frames, STEREO); break;

        case EQ_EFFECT_INDEX:
            eq_process_block(in_l, in_r, frames, STEREO); break;

        case FLNG_EFFECT_INDEX:
            flanger_process_block(in_l, in_r, frames, selected_flanger_mode); break;

        case FZ_EFFECT_INDEX:
            fuzz_process_block(in_l, in_r, frames, STEREO); break;

        case OD_EFFECT_INDEX:
            overdrive_process_block(in_l, in_r, frames, STEREO); break;

        case PHSR_EFFECT_INDEX:
            phaser_process_block(in_l, in_r, frames, selected_phaser_mode); break;

        case PREAMP_EFFECT_INDEX:   // [NEW]
            // Check what preamp processing is required
            switch (selected_preamp_style) {
                case FENDER:
                    fender_preamp_process_block(in_l, in_r, frames, STEREO);    break;
                case VOX_AC:
                    vox_preamp_process_block(in_l, in_r, frames, STEREO);       break;
                case MARSHALL:
                    marshall_preamp_process_block(in_l, in_r, frames, STEREO);  break;
                case SOLDANO:
                    slo_preamp_process_block(in_l, in_r, frames, STEREO);       break;
            } break;

        case REVB_EFFECT_INDEX:
            reverb_process_block(in_l, in_r, frames, true); break;

        case CAB_SIM_EFFECT_INDEX:
            speaker_sim_process_block(in_l, in_r, frames, STEREO); break;

        case TREM_EFFECT_INDEX:
            tremolo_process_block(in_l, in_r, frames, selected_tremolo_mode); break;

        case VIBR_EFFECT_INDEX:
            vibrato_process_block(in_l, in_r, frames, selected_vibrato_mode); break;
        default:
            break;
    }
}

// Split buffers across scratch banks (reduce bus contention)
static __attribute__((aligned(8), section(".scratch_x"))) int32_t buffer_l[AUDIO_BUFFER_FRAMES];
static __attribute__((aligned(8), section(".scratch_y"))) int32_t buffer_r[AUDIO_BUFFER_FRAMES];

// I2S audio processing
__attribute__((section(".time_critical"))) 
static void process_audio(const int32_t* input, int32_t* output, size_t num_frames) {
    
    // Start CPU counter
    if (SHOW_CPU) cpu0_task_start();

    local_peak_left  = 0;
    local_peak_right = 0;

    // De-interleave input
    for (size_t i = 0; i < num_frames; i++) {
        buffer_l[i] = input[i * 2 + 1];             
        if(!STEREO){ buffer_r[i] = buffer_l[i];  } // Input = Mono  
        else{        buffer_r[i] = input[i * 2]; } // Input = Stereo 
    }

    // Check the max inpu value to be shown in the VU meter
    if (currentUI == UI_VU_IN) {
        for (size_t i = 0; i < num_frames; i++) {
            process_audio_clipping(buffer_l[i], buffer_r[i], &local_peak_left, &local_peak_right);
        }
    }

    // RUn effects processing for each effects slot that is enabled
    for (int slot = 0; slot < 3; slot++) {
        if (led_state & (1 << slot)) {
            process_selected_effect_block(slot, buffer_l, buffer_r, num_frames);
        }
    }

    // Apply volume to each sample
    for (size_t i = 0; i < num_frames; i++) {
        process_audio_volume_sample(&buffer_l[i], &buffer_r[i]);
    }


    // Check the max output value to be shown in the VU meter
    if (currentUI == UI_VU_OUT) {
        for (size_t i = 0; i < num_frames; i++) {
            process_audio_clipping(buffer_l[i], buffer_r[i], &local_peak_left, &local_peak_right);
        }
    }
    
    // Check the gain reduction to be shown in the VU meter
    if (currentUI == UI_VU_GAIN) {
        // Just copy gain reduction dB values (already updated per sample)
    }

    // Interleave output
    for (size_t i = 0; i < num_frames; i++) {
        output[i * 2] = buffer_l[i];
        output[i * 2 + 1] = buffer_r[i];
    }

    // End CPU counter
    if (SHOW_CPU) cpu0_task_end();

    // Update peak values for VU meter
    peak_left = local_peak_left;
    peak_right = local_peak_right;
}


// I2S DMA interrupt handler
__attribute__((section(".time_critical"))) 
static void dma_i2s_in_handler(void) {
    /* We're double buffering using chained TCBs. By checking which buffer the
     * DMA is currently reading from, we can identify which buffer it has just
     * finished reading (the completion of which has triggered this interrupt).
     */
    if (*(int32_t**)dma_hw->ch[i2s.dma_ch_in_ctrl].read_addr == i2s.input_buffer) {
        // It is inputting to the second buffer so we can overwrite the first
        process_audio(i2s.input_buffer, i2s.output_buffer, AUDIO_BUFFER_FRAMES);
    } else {
        // It is currently inputting the first buffer, so we write to the second
        process_audio(&i2s.input_buffer[STEREO_BUFFER_SIZE], &i2s.output_buffer[STEREO_BUFFER_SIZE], AUDIO_BUFFER_FRAMES);
    }
    dma_hw->ints0 = 1u << i2s.dma_ch_in_data;  // clear the IRQ
}

// ============================================================================
// === FLASH - button check ===================================================
// ============================================================================

// Returns true while the TAP footswitch is physically held down.
// IMPLEMENT to match your board mapping.
// Example if 'footswitch_state' has TAP on bit 3 (LSB=slot1, slot2, slot3, TAP):
static inline bool tap_button_is_down(void) {
    // If you already expose a boolean for TAP, just return it here.
    const uint8_t TAP_MASK = (1u << 3);
    return (footswitch_state & TAP_MASK) != 0;
}

// ============================================================================
// === IO Actions =============================================================
// ============================================================================

#include "actions.h"

void handle_tap_tempo_button(){
    // --- TAP button: short press = tempo, long hold = save ---
    static bool tap_was_down     = false;
    static uint64_t tap_down_us  = 0;
    static bool saved_this_hold  = false;
    static uint64_t last_tap_us  = 0;   // for tempo

    bool tap = tap_button_is_down();
    uint64_t now_u = time_us_64();

    if (tap && !tap_was_down) {
        // Fresh press edge
        tap_down_us = now_u;
        saved_this_hold = false;
    }

    if (tap && tap_was_down) {
        // Still holding: check duration
        uint64_t held = now_u - tap_down_us;
        if (held >= HOLD_FOR_SAVE && !saved_this_hold) {
            save_request = true;     // trigger once
            saved_this_hold = true;
            if (DEBUG) printf("Long hold → save request!\n");
        }
    }

    if (!tap && tap_was_down) {
        // Released → only count as TAP TEMPO if NOT a long hold
        uint64_t held = now_u - tap_down_us;
        if (held < HOLD_FOR_SAVE && held > 50*1000) { // debounce 50 ms
            if (last_tap_us != 0) {
                uint32_t interval = (now_u - last_tap_us) / 1000; // ms
                if (interval >= 50 && interval <= 2000) {
                    tap_interval_ms = interval;
                    activate_tap_flag = true;
                    if (DEBUG) printf("Short tap → new tempo %u ms\n", tap_interval_ms);
                }
            }
            last_tap_us = now_u;
        }
    }

    tap_was_down = tap;
}

// ============================================================================
// === UI Generation ==========================================================
// ============================================================================

#include "ui_draw.h"

// ============================================================================
// === Debug Information ======================================================
// ============================================================================

// === RAM allocation ===
extern char __StackLimit;   // End of stack
extern char __bss_end__;    // End of static/global data

size_t get_free_ram_bytes(void) {
    return (size_t)(&__StackLimit - &__bss_end__);
}

float get_free_ram_percent(void) {
    return ((float)get_free_ram_bytes() / (264 * 1024.0f)) * 100.0f;
}

// === FLASH allocation ===
extern uint8_t __flash_binary_start;
extern uint8_t __flash_binary_end;

size_t get_flash_used_bytes(void) {
    return (size_t)(&__flash_binary_end - &__flash_binary_start);
}

float get_flash_used_percent(void) {
    const size_t total_flash = 2 * 1024 * 1024;  // 2MB
    return ((float)get_flash_used_bytes() / total_flash) * 100.0f;
}

// === EFFECTS status ===
void print_enabled_effects(void) {
    printf("Enabled effects:");

    for (int slot = 0; slot < 3; slot++) {
        if (led_state & (1 << slot)) {
            int effect_index = selectedEffects[slot];
            if (effect_index >= 0 && effect_index < NUM_EFFECTS) {
                printf("\n - Slot %d: %s ", slot + 1, allEffects[effect_index]);

                // Print the effects mode as well 
                switch (effect_index) {
                    case CHRS_EFFECT_INDEX:
                        printf("- %s", chorus_mode_names[selected_chorus_mode]);   break;
                    case DELAY_EFFECT_INDEX:
                        printf("- %s", delay_mode_names[selected_delay_mode]);     break;
                    case FLNG_EFFECT_INDEX:
                        printf("- %s", stereo_mode_names[selected_flanger_mode]);  break;
                    case PHSR_EFFECT_INDEX:
                        printf("- %s", stereo_mode_names[selected_phaser_mode]);   break;                
                    case PREAMP_EFFECT_INDEX:
                        printf("- %s", preamp_names[selected_preamp_style]);       break;
                    case TREM_EFFECT_INDEX:
                        printf("- %s", stereo_mode_names[selected_tremolo_mode]);  break;
                    case VIBR_EFFECT_INDEX:
                        printf("- %s", stereo_mode_names[selected_vibrato_mode]);  break;
                }
            } else {
                printf("\n - Slot %d: (Invalid effect index: %d)", slot + 1, effect_index);
            }
        }
    }
    printf("\n"); // New Line
}

// ============================================================================
// === Clocks =================================================================
// ============================================================================
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
int main() {
    // Overclock the system 
    setup_system_and_peripheral_clocks();

    // Launch OLED/UI on second core
    multicore_launch_core1(second_thread);
    // Wait for Core 1 to be ready
    while (!dsp_ready) tight_loop_contents();

    // Setup audio
    i2s_program_start_synched(pio0, &i2s_config_default, dma_i2s_in_handler, &i2s);

    // Calculate sample time
    sample_period_us = (1000000.0f * AUDIO_BUFFER_FRAMES) / SAMPLE_RATE;

    while (true) {
        sleep_ms(1);

        // Perform requested save on Core 0
        if (save_request) {
            if(DEBUG) printf("Start saving to flash:\n");
            saving_in_progress = true;
            __sev();
            sleep_ms(5);              // let OLED draw "SAVING..."

            // Wait for core 1 to park
            ui_park_req = true;
            __sev();
            while (!ui_park_ack) { 
                tight_loop_contents();
                sleep_ms(250);
                // if(DEBUG) printf("Waiting for Core1 to park...\n");
            }

            save_all_settings_to_flash();   // <-- no args

            // Wait for core 1 to un-park
            ui_park_req = false;
            __sev();
            while (ui_park_ack) { 
                tight_loop_contents(); 
                sleep_ms(250);
                // if(DEBUG) printf("Waiting for Core1 to un-park...\n");
            }

            saving_in_progress = false;
            save_request = false;

            if(DEBUG) printf("Settings saved to flash!\n");
        }
    }
}

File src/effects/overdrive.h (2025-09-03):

/* overdrive.h
 * Author: Milan Wendt
 * Date:   2025-08-19
 *
 * Copyright (c) 2025 Milan Wendt
 *
 * This file is part of the RP2040-DSP project.
 *
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
 * You should have received a copy of the GNU General Public License along with this project. 
 * If not, see <https://www.gnu.org/licenses/>.
 */#ifndef OVERDRIVE_H 
#define OVERDRIVE_H

#include <stdint.h>

// --- overdrive parameters in Q8.24 ---
static int32_t od_gain          = 0x01000000;
static int32_t od_volume        = 0x01000000;
static int32_t od_low_gain_q24  = 0x01000000;
static int32_t od_mid_gain_q24  = 0x01000000;
static int32_t od_mid_a_q24     = MID_A_Q24;
static int32_t od_high_gain_q24 = 0x01000000;
static int32_t od_asym_q24      = 0x018C28F6;   // Fixed at ~70%


// --- Filter states ---
static int32_t od_low_state_l = 0, od_mid_lp_state_l = 0, od_mid_hp_state_l = 0, od_high_state_l = 0;
static int32_t od_low_state_r = 0, od_mid_lp_state_r = 0, od_mid_hp_state_r = 0, od_high_state_r = 0;
static int32_t od_lpf_state_l = 0, od_lpf_state_r = 0;
static int32_t od_hpf_state_l = 0, od_hpf_state_r = 0;

// --- Approximate cubic soft clip with asymmetry ---
static inline __attribute__((always_inline)) int32_t soft_clip(int32_t x) {
    if (x > 0x01000000) x = 0x01000000;
    if (x < -0x01000000) x = -0x01000000;

    int32_t x2 = (x >> 12) * (x >> 12);
    int32_t x3 = (x2 >> 12) * (x >> 12);

    int32_t cubic;
    if (x >= 0) {
        cubic = x3 / 4;
    } else {
        int64_t num = ((int64_t)x3 << 24);                 // Q8.24 numerator
        int64_t den = 4 * (int64_t)od_asym_q24;
        // sign-aware round-to-nearest
        num += (num >= 0) ? (den >> 1) : -(den >> 1);
        cubic = (int32_t)(num / den);
    }
    return (x - cubic) * 3;
}

// --- Per-channel overdrive processing ---
static inline __attribute__((always_inline)) int32_t process_od_channel(
    int32_t s,
    int32_t *low_state,
    int32_t *mid_lp_state,
    int32_t *mid_hp_state,
    int32_t *high_state,
    int32_t *lpf_state,
    int32_t *hpf_state
) {
    //s = (int32_t)(((int64_t)s * od_gain) >> 24);
    s = qmul(s, od_gain);

    // HPF before clipping to reduce rumble
    s = apply_1pole_hpf(s, hpf_state, HPF_A_Q24);   // Global HPF

    // Clipping
    s = soft_clip(s);

    // LPF after clipping to reduce fizz
    s = apply_1pole_lpf(s, lpf_state, LPF_A_Q24);   // Global LPF

    // Low-shelf
    int32_t low_out = apply_1pole_lpf(s, low_state, BASS_A_Q24); // Global BASS
    //low_out = (int32_t)(((int64_t)low_out * od_low_gain_q24) >> 24);
    low_out = qmul(low_out, od_low_gain_q24);

    // Mid band-pass
    int32_t mid_band = apply_1pole_lpf(
        apply_1pole_hpf(s, mid_hp_state, od_mid_a_q24),
        mid_lp_state, od_mid_a_q24
    );
    //int32_t mid_out = (int32_t)(((int64_t)mid_band * od_mid_gain_q24) >> 24);
    int32_t mid_out = qmul(mid_band, od_mid_gain_q24);

    // High-shelf filter
    int32_t high_out = s - apply_1pole_lpf(s, high_state, TREBLE_A_Q24); // Global TREB
    //high_out = (int32_t)(((int64_t)high_out * od_high_gain_q24) >> 24);
    high_out = qmul(high_out, od_high_gain_q24);

    // Mix Tonestack
    int64_t y = (int64_t)low_out + (int64_t)mid_out + (int64_t)high_out;
    y = y * (int64_t)od_volume;
    y += (y >= 0) ? (1LL<<23) : -(1LL<<23);   // round-to-nearest
    int32_t output = clamp24((int32_t)(y >> 24));
    return output;
}

// --- Process stereo sample ---
static inline void process_audio_overdrive_sample(int32_t* inout_l, int32_t* inout_r, bool stereo) {
    *inout_l = process_od_channel(*inout_l, &od_low_state_l, &od_mid_lp_state_l, &od_mid_hp_state_l, &od_high_state_l, &od_lpf_state_l, &od_hpf_state_l);
    if(!stereo){    *inout_r = *inout_l; } // Process MONO
    else{           *inout_r = process_od_channel(*inout_r, &od_low_state_r, &od_mid_lp_state_r, &od_mid_hp_state_r, &od_high_state_r, &od_lpf_state_r, &od_hpf_state_r);   }
}

// --- Load parameters ---
static inline void load_overdrive_parms_from_memory(void) {
    int32_t pot;

    // Gain from -26dB to 0dB
    pot = storedPotValue[OD_EFFECT_INDEX][0];
    od_gain          = map_pot_to_q24(pot, float_to_q24(0.05f), float_to_q24(1.0f));

    // Bass from -12dB to +6dB
    pot = storedPotValue[OD_EFFECT_INDEX][1];
    od_low_gain_q24  = map_pot_to_q24(pot, float_to_q24(0.25f), float_to_q24(2.0f));

    // Mid from -12dB to +9.5dB
    pot = storedPotValue[OD_EFFECT_INDEX][2];
    od_mid_gain_q24  = map_pot_to_q24(pot, float_to_q24(0.25f), float_to_q24(3.0f));

    // Mid frequency: 400 Hz to 1 kHz
    pot = storedPotValue[OD_EFFECT_INDEX][3];
    od_mid_a_q24 = map_pot_to_q24(pot, 0x0009F15A, 0x001F68E3);

    // Treb from -12dB to +6dB
    pot = storedPotValue[OD_EFFECT_INDEX][4];
    od_high_gain_q24 = map_pot_to_q24(pot, float_to_q24(0.25f), float_to_q24(2.0f));

    // Volume from -6dB to +26dB
    pot = storedPotValue[OD_EFFECT_INDEX][5];
    od_volume        = map_pot_to_q24(pot, float_to_q24(0.5f), float_to_q24(20.0f));

    od_low_state_l = od_mid_lp_state_l = od_mid_hp_state_l = od_high_state_l = 0;
    od_low_state_r = od_mid_lp_state_r = od_mid_hp_state_r = od_high_state_r = 0;
    od_lpf_state_l = od_lpf_state_r = 0;
    od_hpf_state_l = od_hpf_state_r = 0;
}

// --- Update from UI ---
static inline void update_overdrive_params_from_pots(int changed_pot) {
    if (changed_pot < 0 || changed_pot > 5) return;
    storedPotValue[OD_EFFECT_INDEX][changed_pot] = pot_value[changed_pot];
    load_overdrive_parms_from_memory();
}

void overdrive_process_block(int32_t* in_l, int32_t* in_r, size_t frames, bool stereo) {
    for (size_t i = 0; i < frames; i++) {
        process_audio_overdrive_sample(&in_l[i], &in_r[i], stereo);
    }
}

#endif // OVERDRIVE_H

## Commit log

2025-08-19 [Initial Release] Working, but still a long road ahead!
    [CPU Usage Peaks.xlsx, RP2040 - MultEffect Hammond LID v47.stl, RP2040 - MultEffect Hammond v47.stl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]
2025-08-19 Update README.md
    [DOC] Added render of the enclosure and PCB
2025-08-21 [HW] Included V2.0 version of PCB with PCM3060 instead of modules.
    Updated V1.0 to V1.1 with Via stitching and Gnd plane modifications.
    [RP2040-DSP_V2.0-Bottom Layer.gbr, RP2040-DSP_V2.0-Bottom Paste.gbr, RP2040-DSP_V2.0-Bottom Silkscreen.gbr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]
2025-08-22 [PREAMP] Added preamp models for Fender, Vox, Marshall, Soldano
    [STEREO] Added optional setting for Mono | Stereo for all gain and dynamic effects to save CPU
    [I2S] changed buffer size for testing
    Included some helpers for frequency calculation from analog circuits.
    Decided to not go that far into modeling amps to save CPU..
2025-09-03 Update:
    - Flash storage implemented for saving settings
    - Tap button hold (5sec) saves settings fopr next boot
    - Tap tempo implemented for delay
    - Fractions implemented for delay tap tempo
    - LEDs blink according to delay time
    - Optimized compiler and memory for pre-amps
    - Optimized qmul functions for rounding error noise
    - Cleaned-up some code
    - Fixed init routine for delay RAM
    [CPU Usage Peaks.xlsx, Potentiometer mapping.xlsx]
2025-09-07 [FIX] interpolation noise from chorus and flanger fixed
    [OPT] Delay and reverb option to support tails when disabled
    [Flash] Fixed memory sometimes getting initialized as zeros
    [Main.c, chorus.h, delay.h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]
2025-09-08 [PCB] Swapped inputs / outputs so the connections are in line with normal guitar pedal
    [RP2040 - MultEffect V1.1 Case.stl, RP2040 - MultEffect V1.1 Lid.stl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]
2025-09-08 [3D] Models updated
    [RP2040 - MultEffect V1.1 Case.stl, RP2040 - MultEffect V1.1 Lid.stl, RP2040 - MultEffect V1.2 Case.stl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]
2025-09-11 Added manufacturing files and BOM for V1.2
    [BOM_RP2040_DSP_V1.2_DAUGHTER_PCBway.xlsx, BOM_RP2040_DSP_V1.2_MAIN_PCBway.xlsx, BOM_RP2040_DSP_V1.2_PCBway.xlsx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]
2025-09-11 Update README.md
    links to PCBway added
2025-09-11 THT bom with Aliexpress links added
2025-09-11 V2.1 assembly files added
    [BOM_RP2040_DSP_V2.1_DAUGHTER_PCBway.xlsx, BOM_RP2040_DSP_V2.1_MAIN_PCBway.xlsx, BOM_RP2040_DSP_V2.1_PCBway.xlsx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]
2025-09-11 Document for V1.2 ADC module issue added
